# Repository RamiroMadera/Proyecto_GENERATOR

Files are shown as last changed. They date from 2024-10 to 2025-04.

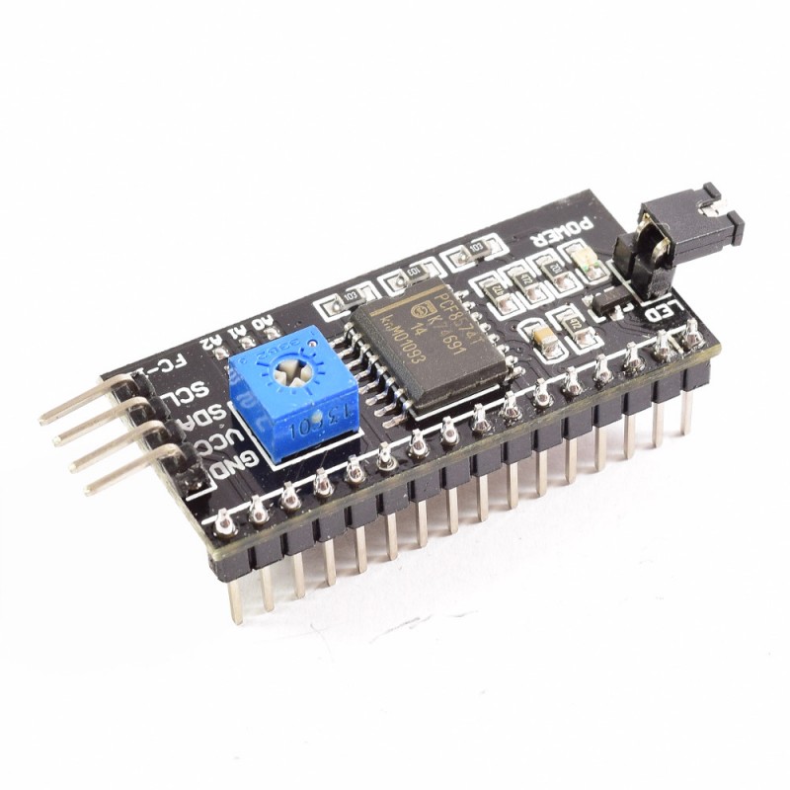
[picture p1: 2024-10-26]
firmware_v3/examples/c/sapi/lcd/lcd_i2c/I2C expander PCF8574/modulo-adaptador-lcd-a-i2c_PCF8574.jpg

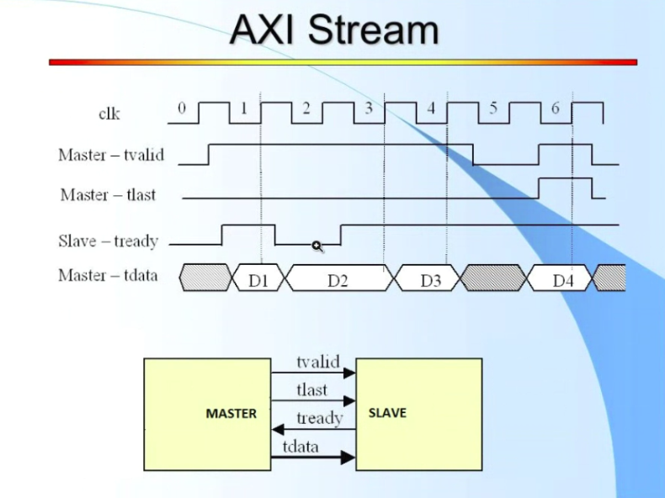
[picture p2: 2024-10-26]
firmware_v3/examples/c/sapi/gpio/axis_interface/AXI Stream.png

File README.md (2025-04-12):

# GENERATOR 🎲  
**Consola electrónica portátil para jugar a la Generala**  
Dispositivo desarrollado con la **EDU-CIAA-NXP** que emula tiradas de dados, combinaciones y puntajes del tradicional juego de Generala. Integra una pantalla táctil, efectos de sonido, sensores de movimiento y una interfaz gráfica atractiva, todo en un sistema autónomo alimentado por batería.

---

## 🎮 Características principales

- **Simulación de tiradas de Generala**
  - Aleatorización de dados entre 1 y 6.
  - Selección de dados para conservar y volver a tirar.
  - Evaluación automática del puntaje y combinaciones.

- **Pantalla gráfica interactiva**
  - Display TFT 2.8" con controlador **ILI9341**.
  - Interfaz táctil basada en **XPT2046** para seleccionar dados y comenzar partidas.

- **Detección de movimiento**
  - Sensor **MPU6050** para identificar la agitación del dispositivo y gatillar la tirada.

- **Sistema de audio**
  - Generación de sonidos con DAC de 10 bits.
  - Amplificación mediante **LM386**.
  - Efectos que acompañan la agitación, la tirada y la obtención de una Generala.

- **Portabilidad total**
  - Alimentado por una batería externa de **5100 mAh**, con una autonomía estimada de más de **16 horas** de juego continuo.

---

## 🧠 Arquitectura del sistema

- **Microcontrolador:** EDU-CIAA-NXP  
- **Interacción por estados:** Inicio → Reposo → Sacudiendo 
- **Firmware en C** desarrollado bajo **CIAA Launcher** 

---

## 📦 Instalación

1. Clona el repositorio:
   ```bash
   git clone https://github.com/RamiroMadera/Proyecto_GENERATOR.git
   ```
2. Abrí el proyecto con CIAA Launcher.
3. Compila y carga el firmware a la placa.
4. Conecta los periféricos según el [esquemático incluido](https://github.com/RamiroMadera/Proyecto_GENERATOR/blob/main/kicad/GENERATOR_Esquematico.pdf).
5. ¡Listo para jugar!

---

## 📚 Documentación técnica

El proyecto cuenta con documentación completa en el informe final del curso "Taller de Proyecto I" de la Facultad de Ingeniería (UNLP), que incluye:

- Requerimientos de hardware y software
- Diseño esquemático y PCB en KiCad
- Arquitectura del firmware y máquina de estados
- Métodos de aleatorización
- Validación del sistema y videos de prueba

[📄 Informe Final (PDF)](https://github.com/RamiroMadera/Proyecto_GENERATOR/blob/main/docs/InformeFinal-Grupo8-TallerDeProyectoI.pdf)

---

## 🧪 Validación y videos

Se ha validado el correcto funcionamiento de todos los requerimientos. Puedes ver los resultados en esta [playlist de YouTube](https://www.youtube.com/playlist?list=PLVBSSKjP-CQ1Y1-SsgbkpVqvSBivJ-5Vr), que muestra:

- Encendido/apagado  
- Tiradas completas  
- Selección de dados  
- Sonido y efectos especiales  
- Reconocimiento de combinaciones y puntajes

---

## 🛠️ Créditos

**Autores:**  
- Tobias Garcia Iacovelli  
- Ramiro Madera  
- Ulises Pereira  

Este proyecto fue desarrollado como parte del curso **Taller de Proyecto I** en la **Facultad de Ingeniería, Universidad Nacional de La Plata**.

---

## 🚀 Próximos pasos

- Añadir sistema de historial de puntajes  
- Incorporar carcasa protectora  
- Expansión a múltiples juegos de dados  
- Conectividad en red para multijugador o leaderboard en la nube

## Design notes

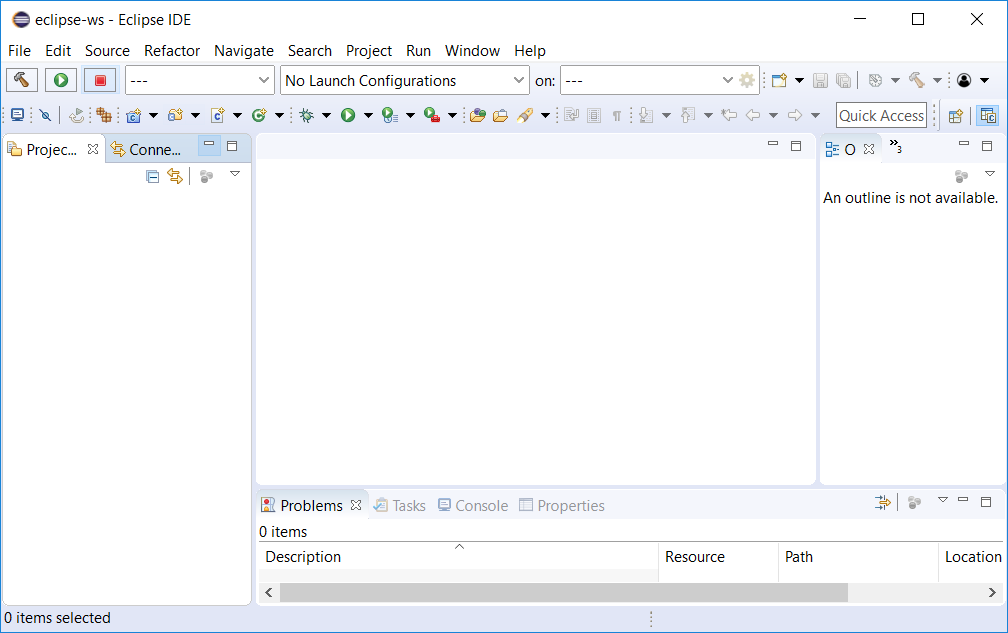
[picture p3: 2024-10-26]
firmware_v3/documentation/firmware/eclipse/Eclipse-Win03.png

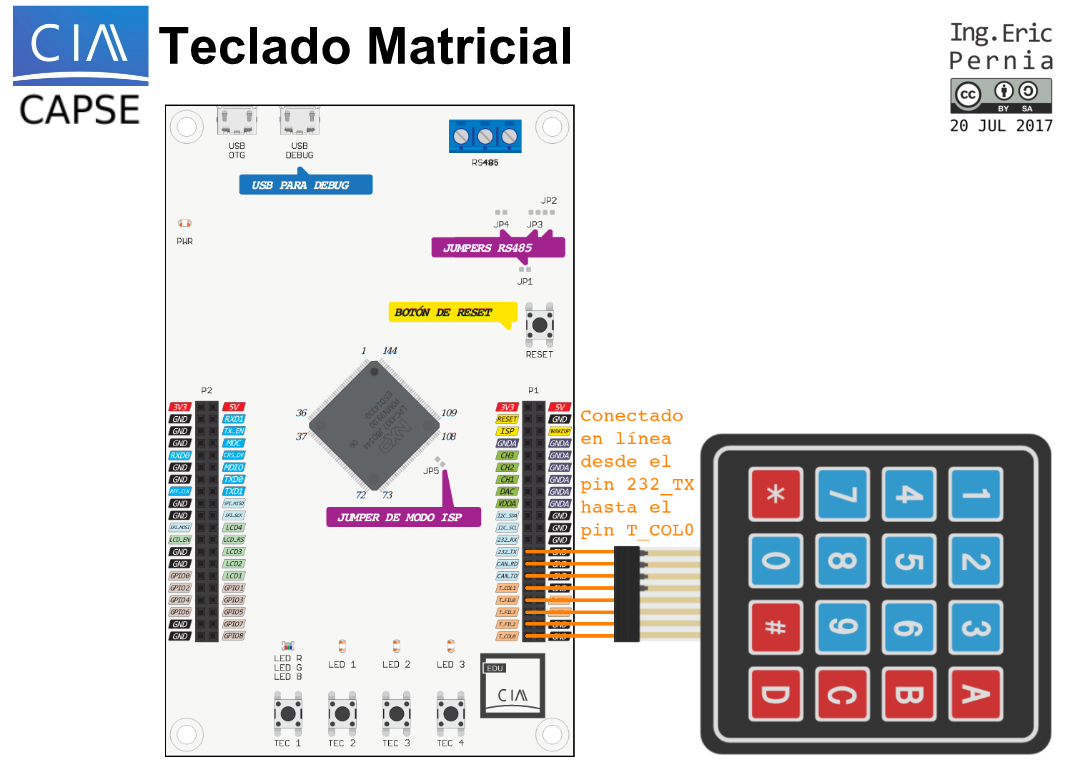
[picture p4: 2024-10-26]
firmware_v3/examples/c/sapi/usb/device/hid_numeric_keypad/Keypad - EDU-CIAA-NXP.png

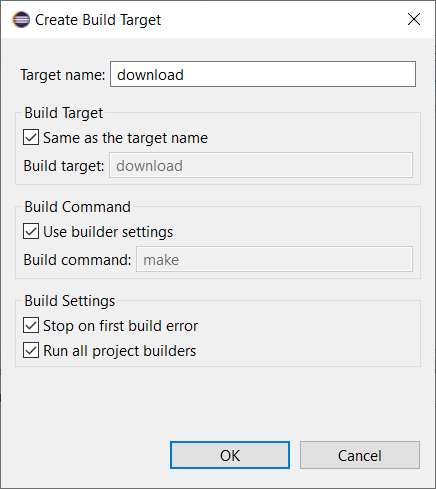
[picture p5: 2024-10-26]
firmware_v3/documentation/firmware/eclipse/targets-04.png

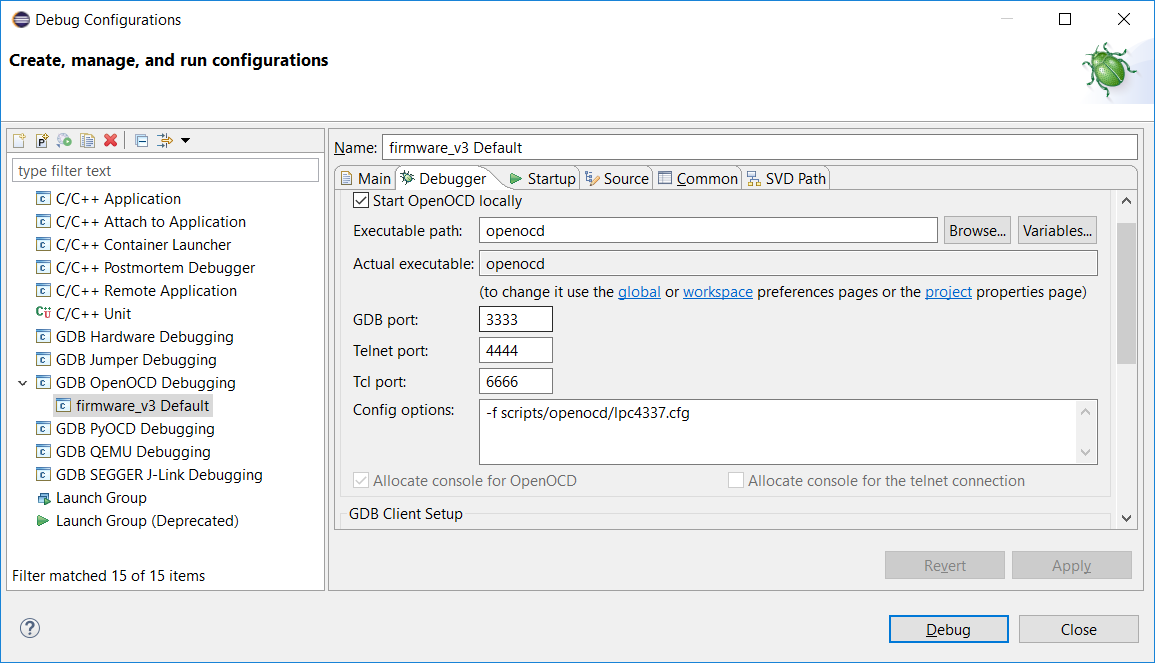
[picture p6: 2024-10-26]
firmware_v3/documentation/firmware/eclipse/Eclipse-Win18.png

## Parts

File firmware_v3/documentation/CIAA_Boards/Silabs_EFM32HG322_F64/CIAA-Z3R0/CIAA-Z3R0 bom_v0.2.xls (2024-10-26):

Reference | Quantity | Value | Footprint | Part number | digikey part number
C12 | 1 | 4.7u | Capacitor 0603 | CC0603KRX5R7BB475 | 311-1785-1-ND
C2 C3 C4 C5 C6 | 5 | 100n | Capacitor 0603 | CC0603KRX7R7BB104 | 311-1088-1-ND
C8 | 1 | 10u | Capacitor 0603 | GRM188R61C106KAALD | 490-10728-1-ND
C1 C10 C11 C7 C9 | 5 | 1u | Capacitor 0603 | CC0603KRX7R7BB105 | 311-1446-1-ND
D1 D3 | 2 | LED GREEN | LED 0805 | LTST-C170GKT | 160-1179-1-ND
D2 | 1 | PMEG2005CT | SOT-23-3 | PMEG2005CT,215 | 1727-5188-1-ND
D4 | 1 | SD0603S040S0R2 | Diode 0603 | SD0603S040S0R2 | 478-7798-1-ND
U1 | 1 | EFM32HG-48LQFP | LQFP-48 7x7mm Pitch 0.5mm | EFM32HG322F64G-B-QFP48 | 336-3835-ND
U2 | 1 | SPX3819M5-L-3-3 | SOT-23-5 | SPX3819M5-L-3-3/TR | 1016-1873-1-ND
U3 | 1 | USBLC6-2 | SOT-23-6 | USBLC6-2SC6 | 497-5235-1-ND
SW1 SW2 | 2 | Switch EVQ-PE105K | Switch SPST-NO 6mm x 3.5mm | EVQ-PE105K | P13594SCT-ND
J3 | 1 | USB Micro-B | USB_Micro-B_Molex_47346-0001 | Molex 473460001 | WM17141CT-ND
J4 | 1 | Header SMD 2x2 Pitch 2.54mm | Pin Header 2x2 Pitch 2.54mm SMD | M20-8760242 | 952-3254-ND
R1 R2 | 2 | 15R | Resistor 0603 | RC0603JR-0715RL | 311-15GRCT-ND
R3 R4 R5 R6 | 4 | 1K | Resistor 0603 | RC0603JR-0710KL | 311-10KGRCT-ND

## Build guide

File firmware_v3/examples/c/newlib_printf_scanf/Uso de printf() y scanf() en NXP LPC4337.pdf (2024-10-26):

# Uso de printf() y scanf() en el microcontrolador NXP LPC4337

# Biblioteca newlib, printf() y scanf() completas o reducidas

La biblioteca estándar de C llamada newlib, que incluye el compilador arm-none-eabi del NXP LPC4337 (el microcontrolador que tiene al EDU-CIAA-NXP o la CIAA-NXP) permite utilizar printf() y scanf() con el microcontrolador.

La biblioteca newlib permite ser compilada en 2 versiones. Una versión completa y una versión reducida nombrada newlib nano.

Si se utiliza newlib nano printf() y scanf() no permiten imprimir o recibir valores en punto flotante (float).

Para desactivar newlib nano y que compila la new lib completa en la carpeta app del proyecto, el archivo config.mk poner:

USE_NANO=n

Por defecto viene en y (que si use nano).

De esta manera podemos poner en un programa:

printf( "Pi vale aproximadamente %f\n", 3.14 );

scanf() y printf() utilizan la UART2 del microcontrolador (UART_USB en la sAPI) como entrada/salida estándar por lo que no se debería reconfigurar la UART2, la está configurada por defecto a 115200 baudios. Esto se hace en el startup del microcontroaldor.

Entonces un programa básico que utilice printf() puede ser simplemente:

#include "sapi.h" // <= Biblioteca sAPI, o alternativamente puede

| // usarse board.h que incluye LPCOpen
int main( void )
{
printf( "Pi vale aproximadamente %f\n", 3.14 ); while( TRUE );
return 0;
}

NOTA:

Si usan printf() en un microcontrolador van a notar que no imprime directamente (envía directo a la UART) si no que lo hace a través de un buffer el cual se envía a la salida estándar, en nuestro caso la UART.

En un programa en la PC si no hay \n este buffer se envía a la salida estándar cuando se llama a la función fflush(), la cual por ejemplo se llama cuando termina el programa.

En embebidos el programa no termina nunca (por el while(1)), entonces hay que forzar el fflush de 2 formas:

1. Llamando a la función fflush():

fflush(stdout);

2. Con \n dentro del texto de printf()

printf( "Hola\n" );

# Uso de memorias del microcontrolador

Se puede probar compilar el mismo programa con la opción USE_NANO en "y" y también en "n" y observar la diferencia de ocupación de memorias.

### Con newlib nano

text | data | bss | dec | hex filename
11460 | 300 | 76 | 11836 | 2e3c app/out/app.elf

En este caso printf() no imprime los valores float %f, pero no da errores, simplemente los ignora.

### Con newlib completa

text | data | bss | dec | hex filename
28992 | 2676 | 152 | 31820 | 7c4c app/out/app.elf

En este caso printf() funciona con todas sus características.

Para comprender esos números, todos están en bytes y representan:

- text - contiene el código compilado y datos de sólo lectura (read-only) de la aplicación (el valor de bytes está en decimal).
- data - shows the read-write data in your application (el valor de bytes está en decimal).
- bss - Muestra los datos inicializados con 0 ('bss' y 'common') en la aplicación (el valor de bytes está en decimal).
- dec - Total = 'text' + 'data' + 'bss' (el valor de bytes está en decimal).
- hex - El valor de bytes en hexadecimal equivalente al de 'dec'.

Esto típicamente se interpreta como:

- Consumo de FLASH de la aplicación equivale a text + data.
- Consumo de RAM de la aplicación equivale a data + bss.

Más información en: http://www.support.code-red-tech.com/CodeRedWiki/FlashRamSize

Como puede observarse, newlib completa ocupa muchos más recursos.

# Uso de printf() y scanf()

## printf()

Las funciones de la familia printf producen una salida de acuerdo a format como se describe abajo. Printf y vprintf escriben su salida a stdout, el flujo de salida estándar. fprintf y vfprintf escriben su salida al stream de salida dado. sprintf, snprintf, vsprintf y vsnprintf escriben a una cadena de caracteres str.

### Prototipo o declaración

int printf( const char *format, ... );

### Ejemplos

printf("Strings:\n");
const char* s = "Hello";
printf("\t.%10s.\n\t.%-10s.\n\t.%*s.\n", s, s, 10, s);

printf("Characters:\t%c %%\n", 65);

printf("Integers\n");
printf("Decimal:\t%i %d %.6i %i %.0i %+i %u\n",1,2,3,0,0,4,-1); printf("Hexadecimal:\t%x %x %X %#x\n", 5, 10, 10, 6); printf("Octal:\t%o %#o %#o\n", 10, 10, 4);

printf("Floating point\n");
printf("Rounding:\t%f %.0f %.32f\n", 1.5, 1.5, 1.3); printf("Padding:\t%05.2f %.2f %5.2f\n", 1.5, 1.5, 1.5); printf("Scientific:\t%E %e\n", 1.5, 1.5); printf("Hexadecimal:\t%a %A\n", 1.5, 1.5);

### Los caracteres % (especificaciones de conversión)

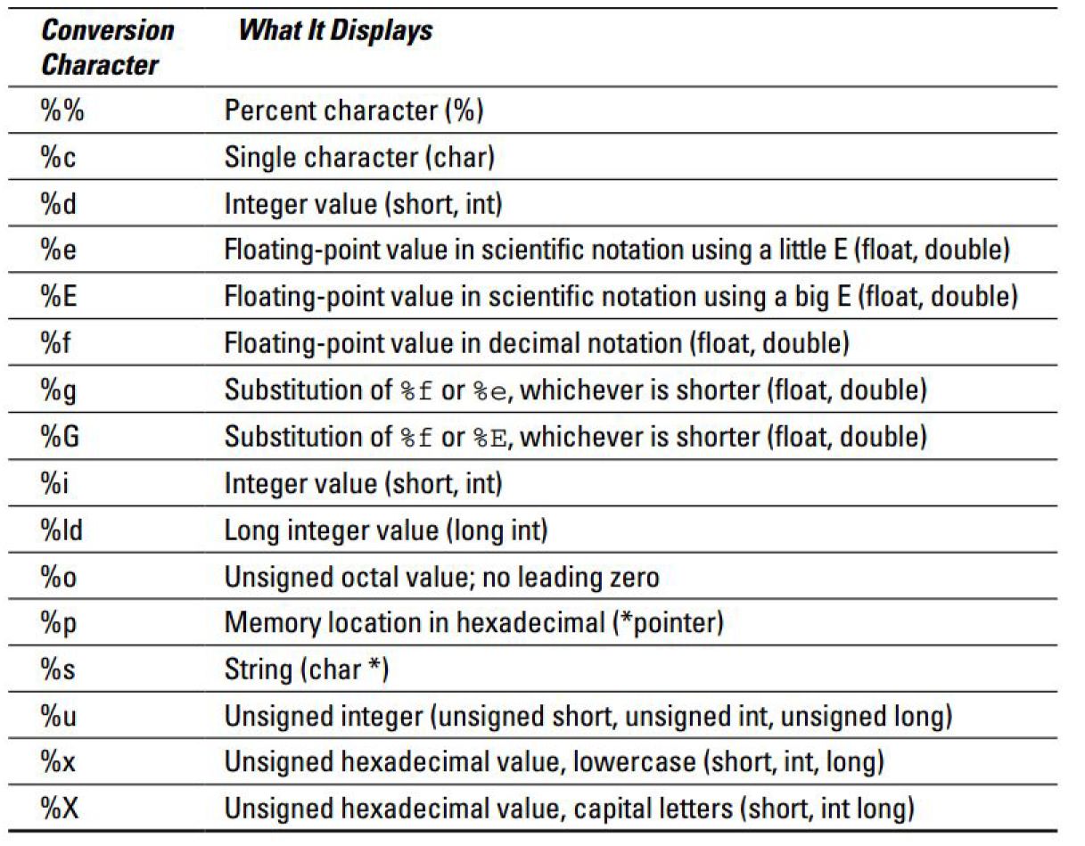
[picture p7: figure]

### Más información

- http://es.tldp.org/Paginas-manual/man-pages-es-1.28/man3/printf.3.html
- https://es.cppreference.com/w/c/io/fprintf

## scanf()

La familia scanf de funciones busca en la entrada según un formato como se describe más adelante. Este formato puede contener especificadores de conversión; los resultados de tales conversiones, si las hay, se guardan donde apunten los argumentos punteros. La
función scanf | lee la entrada del flujo de entrada estándar stdin, fscanf | lee su entrada del
puntero a FILE flujo, y sscanf | lee su entrada de la cadena de caracteres a la que apunte str.

### Prototipo o declaración

int scanf( const char *format, ... );

### Ejemplo

char text[50];
printf( "Ingrese un texto y presione enter:\r\n" ); scanf( "%s", text );
printf( "El texto ingresado es: %s\r\n", text );

### Los carcateres % (especificaciones de conversión)

%c para indicar entrada de un caracter
%d para indicar entrada de un entero
%f para indicar entrada de un flotante
%s para indicar entrada de un string

### Sugerencias para el uso de scanf()

- Antes de usar scanf, imprimir con printf() indicando al usuario qué tipo de dato o información debe ingresar.
- Ingresar de a un dato por vez. Será mejor que cada llamado a scanf() sea para ingresar un dato, evitar el ingreso múltiple.
- Para ingresar texto, indicar el máximo de caracteres que scanf() debe aceptar, así no almacena en zonas inapropiadas.

### Más información

- http://es.tldp.org/Paginas-manual/man-pages-es-1.28/man3/scanf.3.html
- https://es.cppreference.com/w/c/io/fscanf

# Ejemplo con scanf() y printf()

#include "sapi.h" // <= Biblioteca sAPI, o alternativamente puede // usarse board.h que incluye LPCOpen

// La UART_USB se inicializa en el startup del microcontrolador a // 115200 baudios para salida y entrada estandar.

// Recordar en config.mk poner USE_NANO=n (usar newlib completa // en lugar de newlib nano) para tener soporte de flotantes en // printf(), sin embargo, esto causa que el programa ocupe MUCHA // mas RAM y FLASH.

int main( void )
{
printf( "Pi vale aproximadamente %f\r\n", 3.14 );

char text[50];
int num;

printf( "Ingrese un texto y presione enter:\r\n" ); scanf( "%s", text );
printf( "El texto ingresado es: %s\r\n", text );

printf( "Ingrese un numero y presione enter:\r\n" ); scanf( "%d", &num );
printf( "El numero ingresado es: %d\r\n", num );

while( TRUE );

return 0;
}

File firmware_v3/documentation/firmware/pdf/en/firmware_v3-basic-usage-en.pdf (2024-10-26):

# firmware_v3 usage

Make sure you have an arm-none-eabi-* toolchain configured in your PATH . If you don't have it, download GCC ARM Embedded. (https://developer.arm.com/open-source/gnu-toolchain/gnu-rm)
Make sure you have an openocd configured in your PATH .

# Select a target board to compile

Create a board.mk text file inside this folder.
Define BOARD variable in board.mk according to the board you want to compile. board.mk example default values:

Note: If you have zenity installed (included in CIAA Software), (https://github.com/epernia/software/) you can use:

make select_board to select graphically a target board.

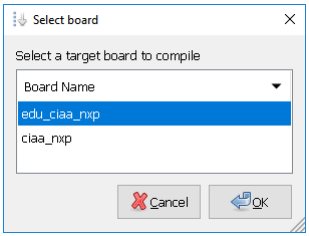
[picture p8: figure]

This will create automaticaly a board.mk text file inside this folder with the selected board.

# Select a program to compile

Create a program.mk text file inside this folder.
Define PROGRAM_NAME and PROGRAM_PATH variables in program.mk according to the program you want to compile (PROGRAM_PATH is relative to this folder, leave void if the

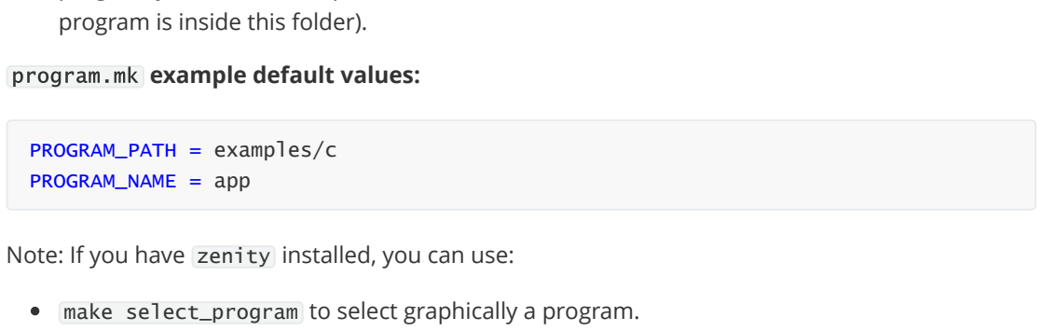
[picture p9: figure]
program is inside this folder).; program.mk example default values:; PROGRAM_PATH = examples/c; PROGRAM_NAME = app

Note: If you have zenity installed, you can use:

make select_program to select graphically a program.

BOARD = edu_ciaa_nxp

This will create automaticaly a program.mk text file inside this folder with the selected program.

# Compile and download

Compile with make .
Download to target via OpenOCD with make download . Clean compilation with make clean .

# Create a new program

Each program consist in a folder (with a non-spaces name) that includes inside 2 folders, one named src (here go, .c, .cpp or .s source code files), and another one named inc (here go, .h or

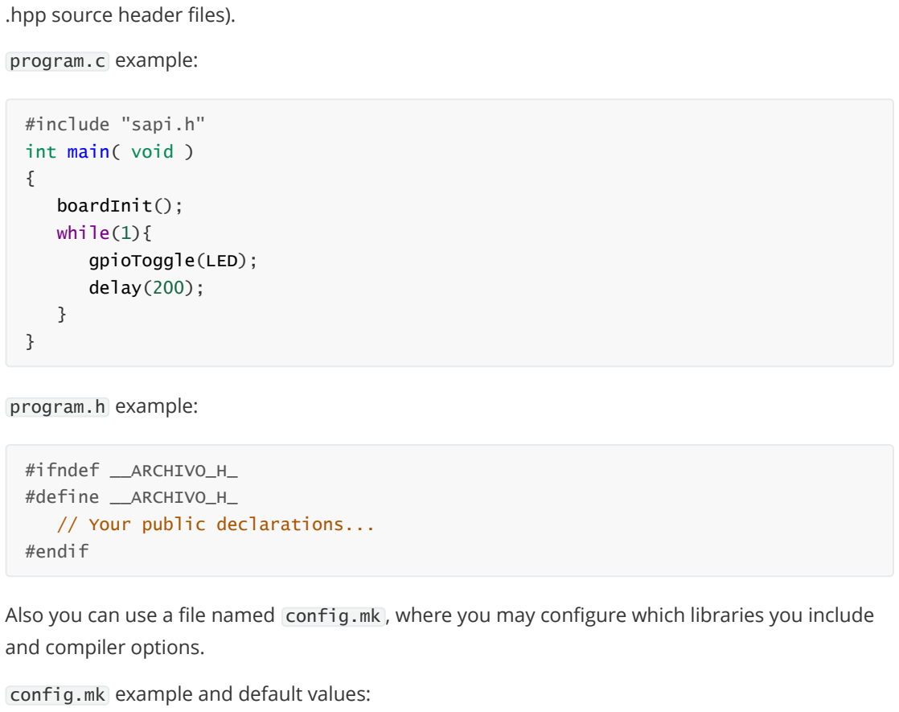
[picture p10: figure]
.hpp source header files).; program.c example:; program.h example:; and compiler options.; config.mk example and default values:; #include "sapi.h"; int main( void ); boardInit();; while(1){; gpioToggle(LED);; delay(200);; #ifndef __ARCHIVO_H_; #define __ARCHIVO_H_; // Your public declarations... #endif

Also you can use a file named config.mk , where you may configure which libraries you include

Program complete structure is:

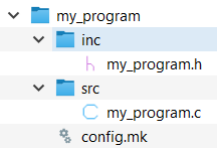
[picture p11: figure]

Note: If you have zenity installed, you can use:

make new_program to create graphically a program using program templates.

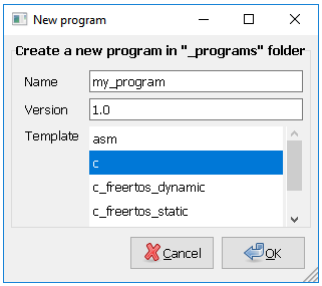
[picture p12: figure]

Note: First time will ask you for your user preferences:

# Compile options

VERBOSE=n
OPT=g
USE_NANO=y
SEMIHOST=n
USE_FPU=y
# Libraries

USE_LPCOPEN=y
USE_SAPI=y

# Create a new global library

The libs folder include libraries that can be used fom any program (global libraries).

The Makefile allow you to include 2 types of libraries:

Simple library. Consist in a folder (with a non-spaces name) that includes inside 2 folders, one named src (here go .c, .cpp or .s source code files), and another one named inc (here go .h or .hpp header files). This kind of library compiles automaticaly by the Makefile. Advanced library. Consist in a library with a complex folder and files structure, i.e. LibUSB. This case require make your own makefile. You can inspire from sAPI makefile to do that.

# More information

Back to README.

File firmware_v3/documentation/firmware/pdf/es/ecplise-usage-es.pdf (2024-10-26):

# Índice

Utilización de firmware_v3 con Eclipse
1. Abrir proyecto firmware_v3 en Eclipse
1.1. Abrir proyecto firmware_v3 en Eclipse por primera vez
1.1.1. Iniciar Eclipse
1.1.2. Workspace
1.1.3. Ventana inicial
1.1.4. Abrir Proyecto de Firmware para programar en asembler, C o C++
1.2. Abrir proyecto firmware_v3 en Eclipse en sucesivas ocasiones
2. Compilar proyecto firmware_v3 en Eclipse
2.1. Configurar opciones de compilación
2.2. Compilar proyecto
3. Configurar y ejecutar targets de makefile en Eclipse
3.1. Targets por defecto en Eclipse
3.2. Configurar targets de makefile en Eclipse
4. Depuración de un programa sobre la plataforma de hardware con Eclipse y firmware_v3
4.1. Configuración de la descarga y depuración del programa sobre el hardware
4.2. Probar el funcionamiento de la depuración sobre el hardware
4.3. Botones de control de ejecución y breakpoints
4.4. Depurar otro programa dentro del mismo proyecto

# Utilización de firmware_v3 con Eclipse

# 1. Abrir proyecto firmware_v3 en Eclipse

## 1.1. Abrir proyecto firmware_v3 en Eclipse por primera vez

### 1.1.1. Iniciar Eclipse

Recordar iniciar Eclipse desde el Launcher. Esto traerá las variables de entorno necesarias para ubicar las herramientas externas para compilación y depuración.

### 1.1.2. Workspace

Al abrir el Eclipse solicita seleccionar la carpeta a utilizar como espacio de trabajo (Workspace), elegir dentro de la ruta donde descomprimieron el Launcher la carpeta:

<rutaDondeDescomprimiElLauncher>/workspaces/eclipse-ws

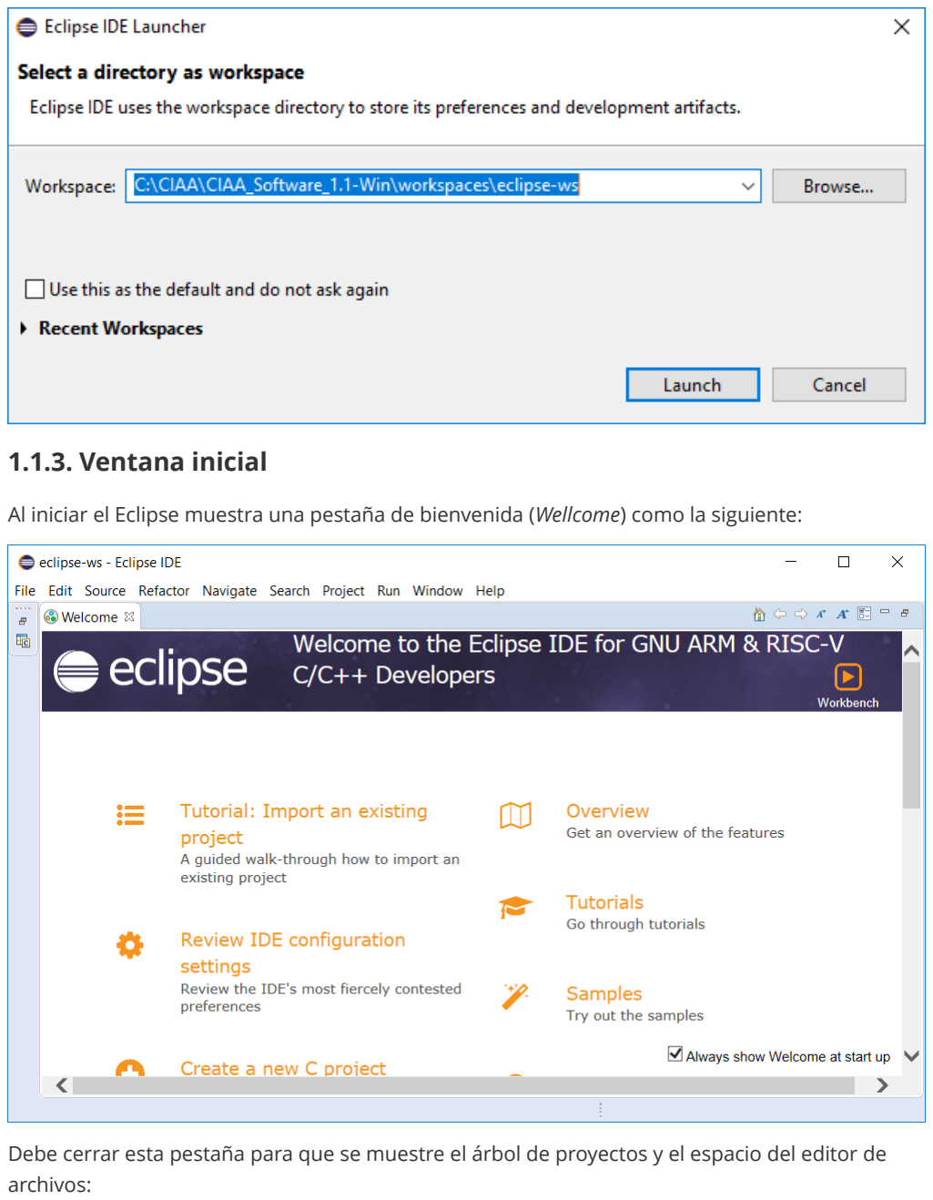
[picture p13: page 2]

### 1.1.3. Ventana inicial

Al iniciar el Eclipse muestra una pestaña de bienvenida (Wellcome) como la siguiente:

Debe cerrar esta pestaña para que se muestre el árbol de proyectos y el espacio del editor de archivos:

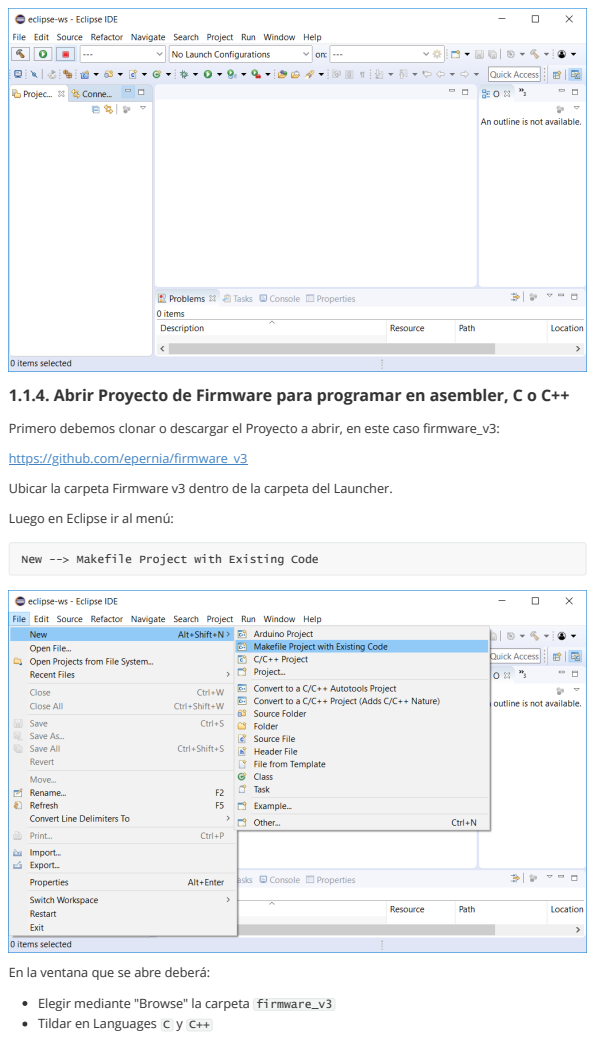
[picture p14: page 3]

1.1.4. Abrir Proyecto de Firmware para programar en asembler, C o C++

Primero debemos clonar o descargar el Proyecto a abrir, en este caso firmware_v3:
https://github.com/epernia/firmware_v3
Ubicar la carpeta Firmware v3 dentro de la carpeta del Launcher.
Luego en Eclipse ir al menú:

New --> Makefile Project with Existing Code

En la ventana que se abre deberá:
Elegir mediante "Browse" la carpeta firmware_v3
Tildar en Languages C y C++

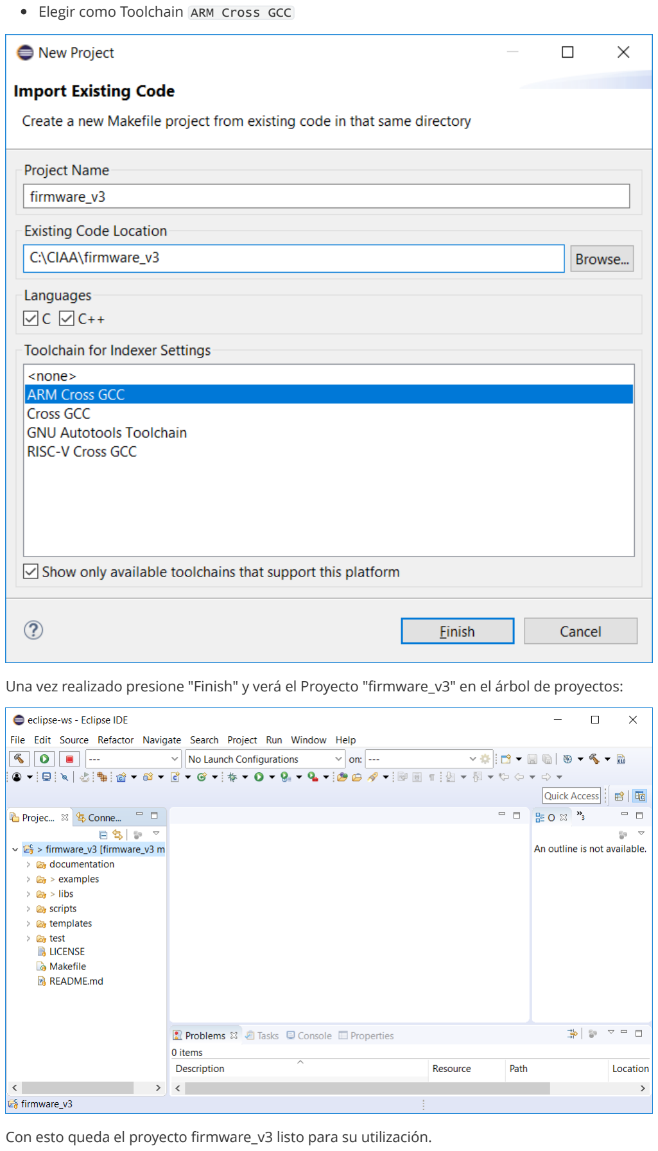
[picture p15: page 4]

Elegir como Toolchain ARM Cross GCC

Una vez realizado presione "Finish" y verá el Proyecto "firmware_v3" en el árbol de proyectos:

Con esto queda el proyecto firmware_v3 listo para su utilización.

Nota: Eclipse puede tener múltiples proyectos en simultáneo dentro de un mismo Workspace. En particular, el proyecto firmware_v3 es un único proyecto que se compone de múltiples programas (los ejemplos que trae más los programas que realizaremos nosotros). Es decir con un único proyecto de Eclipse abierto tendremos la posibilidad de seleccionar que programa del mismo se desea compilar y descargar a la plataforma de hardware.

## 1.2. Abrir proyecto firmware_v3 en Eclipse en sucesivas ocasiones

Eclipse guarda todas las configuraciones realizadas sobre la carpeta elegida como Workspace con y de esta manera al abrir nuevamente Eclipse y seleccionar el Workspace que hemos creado se cargará el proyecto firmware_v3 automáticamente.

# 2. Compilar proyecto firmware_v3 en Eclipse

## 2.1. Configurar opciones de compilación

Se debe hacer click derecho sobre el proyecto "firmware_v3" y luego en la opción "Properties":

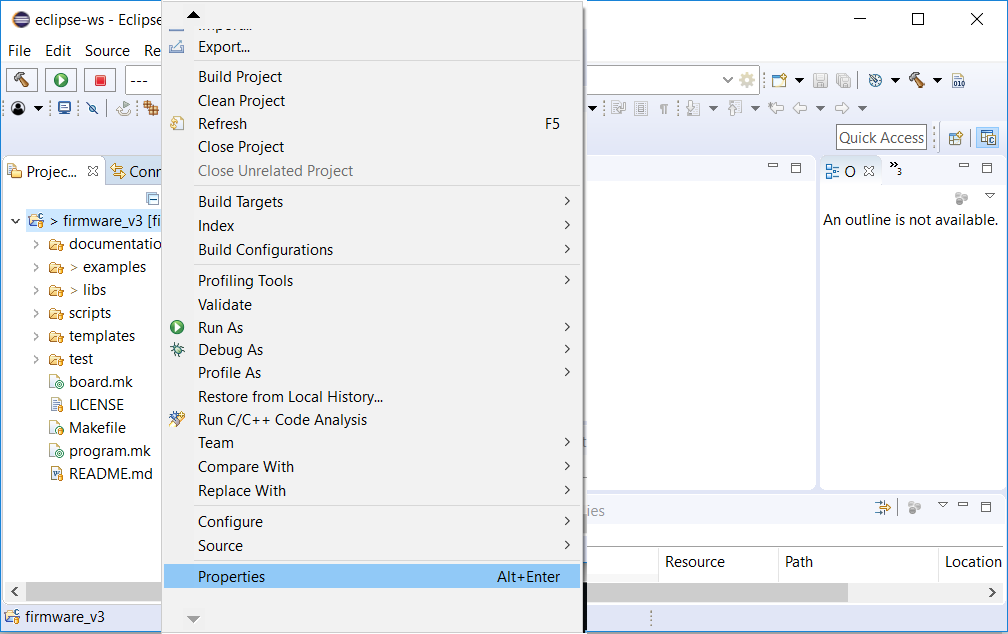
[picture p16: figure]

En la ventana que se abre debe hacer click sobre "C/C++ Build" y en la parte derecha debe: Destildar la opción "Use default build command".
En "Build command" escribir make en el campo de texto.

Presionar "Apply and Close" para aplicar la configuración.

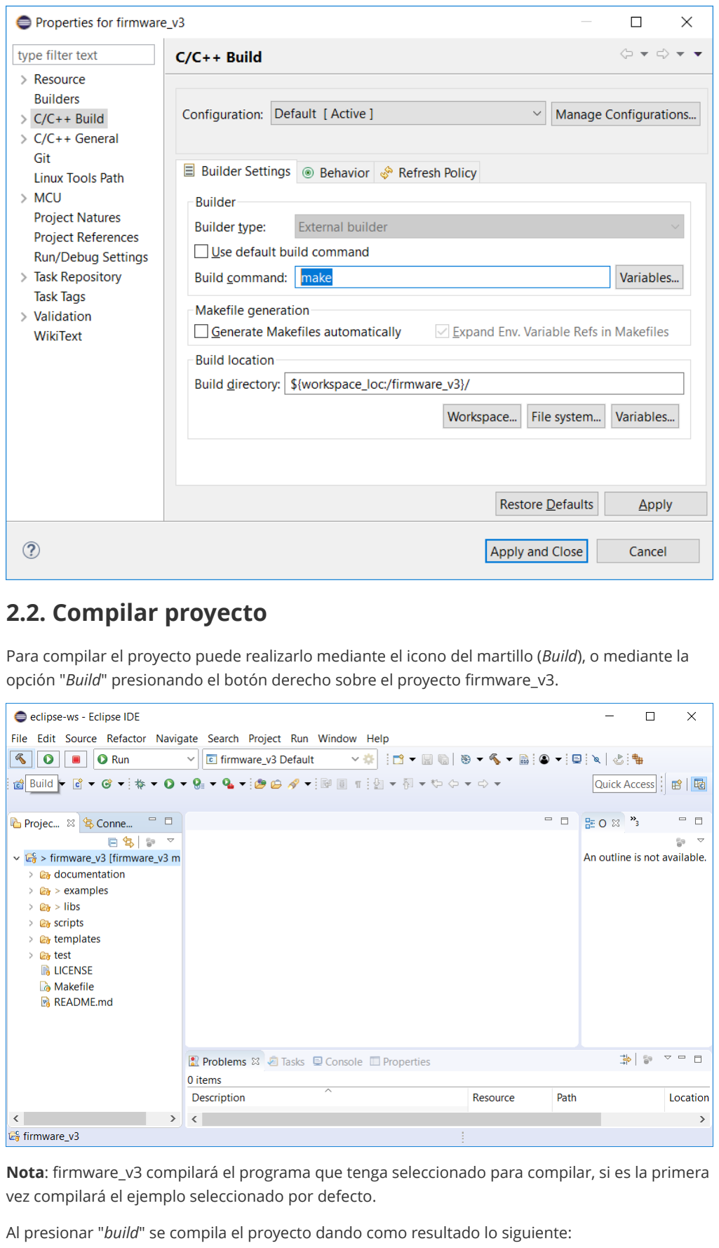
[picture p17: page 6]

## 2.2. Compilar proyecto

Para compilar el proyecto puede realizarlo mediante el icono del martillo (Build), o mediante la opción "Build" presionando el botón derecho sobre el proyecto firmware_v3.

Nota: firmware_v3 compilará el programa que tenga seleccionado para compilar, si es la primera vez compilará el ejemplo seleccionado por defecto.
Al presionar "build" se compila el proyecto dando como resultado lo siguiente:

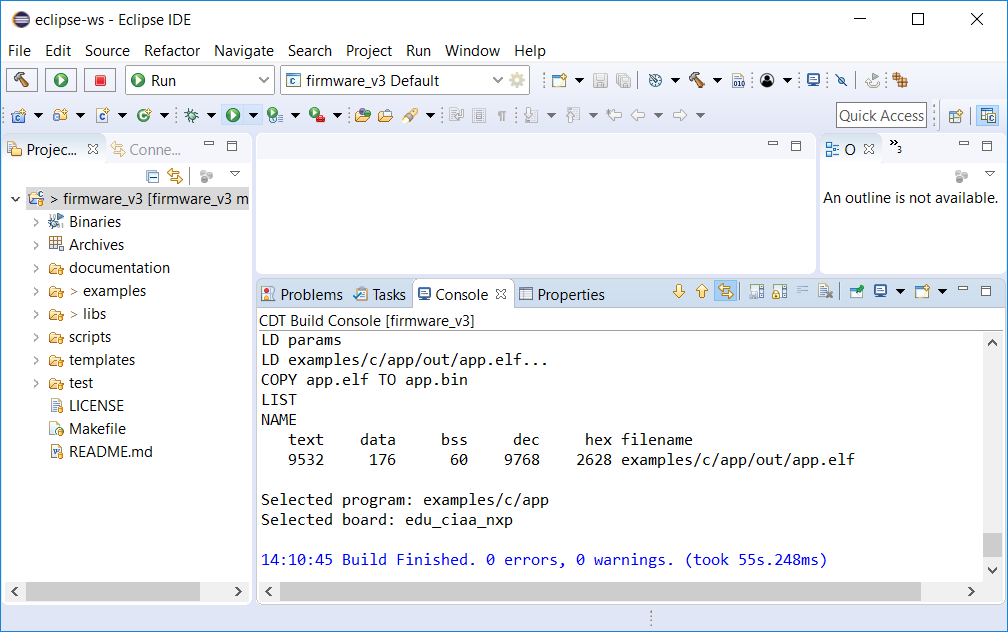
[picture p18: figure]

Nota: observe que se ve:
Los bytes ocupados en cada área de memoria (ver apunte de printf() y scanf() para comprenderlo).
El programa que fue compilado dentro del proyecto, en este caso llamado "app" en la carpeta "examples/c" dentro de "firmware_v3".
La plataforma de hardware para la cual se compiló el programa, en este caso "EDU-CIAA-NXP".

# 3. Configurar y ejecutar targets de de makefile en Eclipse

## 3.1. Targets por defecto en Eclipse

Eclipse muestra algunos de sus targets de diferentes maneras:
El target all como el "botón del martillo" (Build project) accesible desde el menú superior.

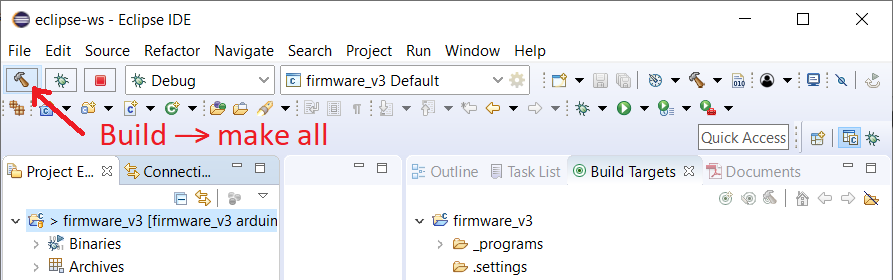
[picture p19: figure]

El botón build ejecuta el comando:

make all
Si se presiona botón derecho del mouse sobre el proyecto firmware_v3 se muestran como opciones del menú contextual:
Build Project. Ejecuta el comando make all

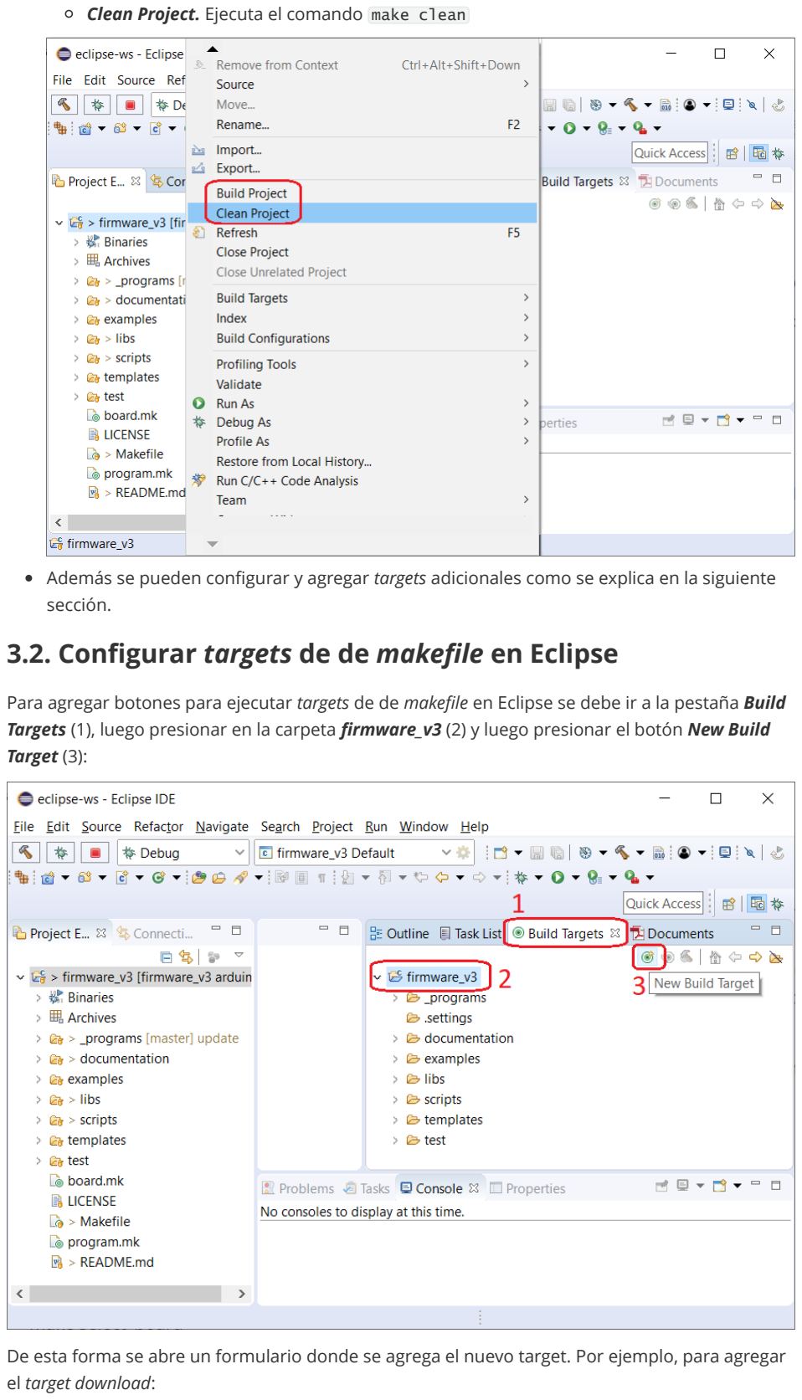
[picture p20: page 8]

Clean Project. Ejecuta el comando make clean

Además se pueden configurar y agregar targets adicionales como se explica en la siguiente sección.

## 3.2. Configurar targets de de makefile en Eclipse

Para agregar botones para ejecutar targets de de makefile en Eclipse se debe ir a la pestaña Build Targets (1), luego presionar en la carpeta firmware_v3 (2) y luego presionar el botón New Build Target (3):

De esta forma se abre un formulario donde se agrega el nuevo target. Por ejemplo, para agregar el target download:

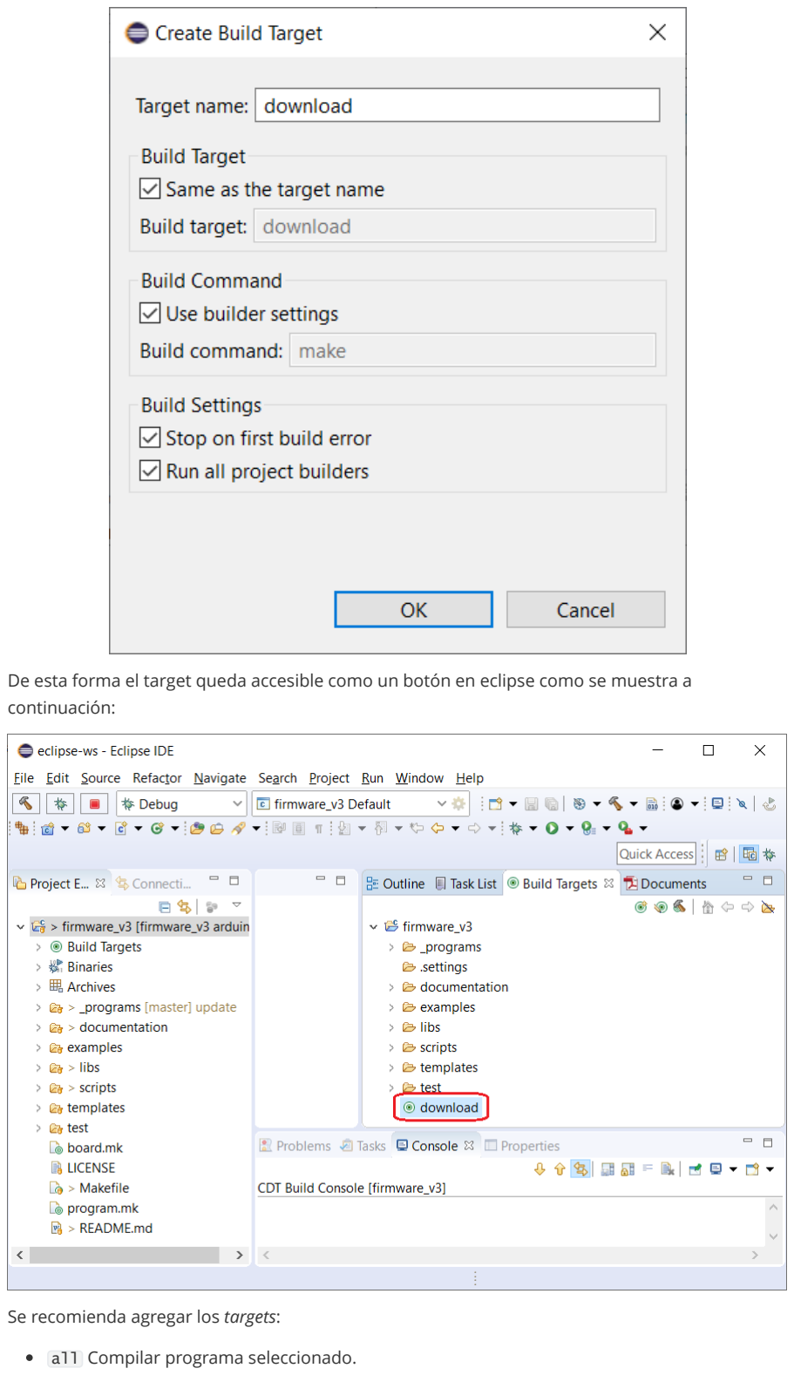
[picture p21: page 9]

De esta forma el target queda accesible como un botón en eclipse como se muestra a continuación:

Se recomienda agregar los targets:

all Compilar programa seleccionado.

clean Eliminar archivos de compilaciones previas (remueve la carpeta out dentro del programa seleccionado). Es necesario ejecutarlo sobre le programa seleccionado al cambiar opciones de compilación del programa (archivo config.mk) o al cambiar la plataforma de hardware (board) para la cual se compilará el programa.
clean_all Eliminar archivos de compilaciones previas de todos los programas dentro de la carpeta firmware_v3.
download Descarga el programa seleccionado a la board seleccionada.
erase Borra la flash de la board seleccionada. Es necesario resetear la plataforma luego de aplicarlo.
new_program Permite gráficamente crear un nuevo programa dentro de la carpeta seleccionada por el usuario (la primera vez se pide el nombre de la carpeta donde se guardaran los programas y se crea dentro de la carpeta firmware_v3).
select_board Permite elegir gráficamente la plataforma de hardware (board) para la cual se compilará el programa.
select_program Permite elegir gráficamente el programa a utilizar (compilar, descargar, limpiar, etc.).
Se ejecutan realizando doble doble click sobre el icono de los mismos.

# 4. Depuración de un programa sobre la plataforma de hardware con Eclipse y firmware_v3

## 4.1. Configuración de la descarga y depuración del programa sobre el hardware

Ubique el ícono del bicho verde (debug) , presione sobre la flecha hacia abajo a la derecha de este icono y en la ventana que se despliega la opción "Debug Configurations..."

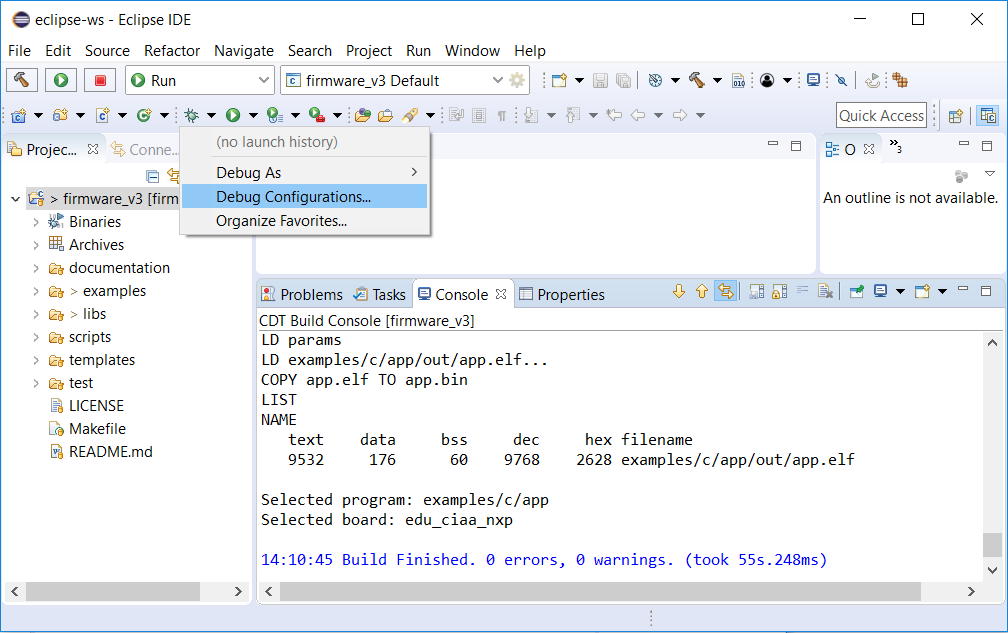
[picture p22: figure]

Esto abre la ventana de configuraciones:

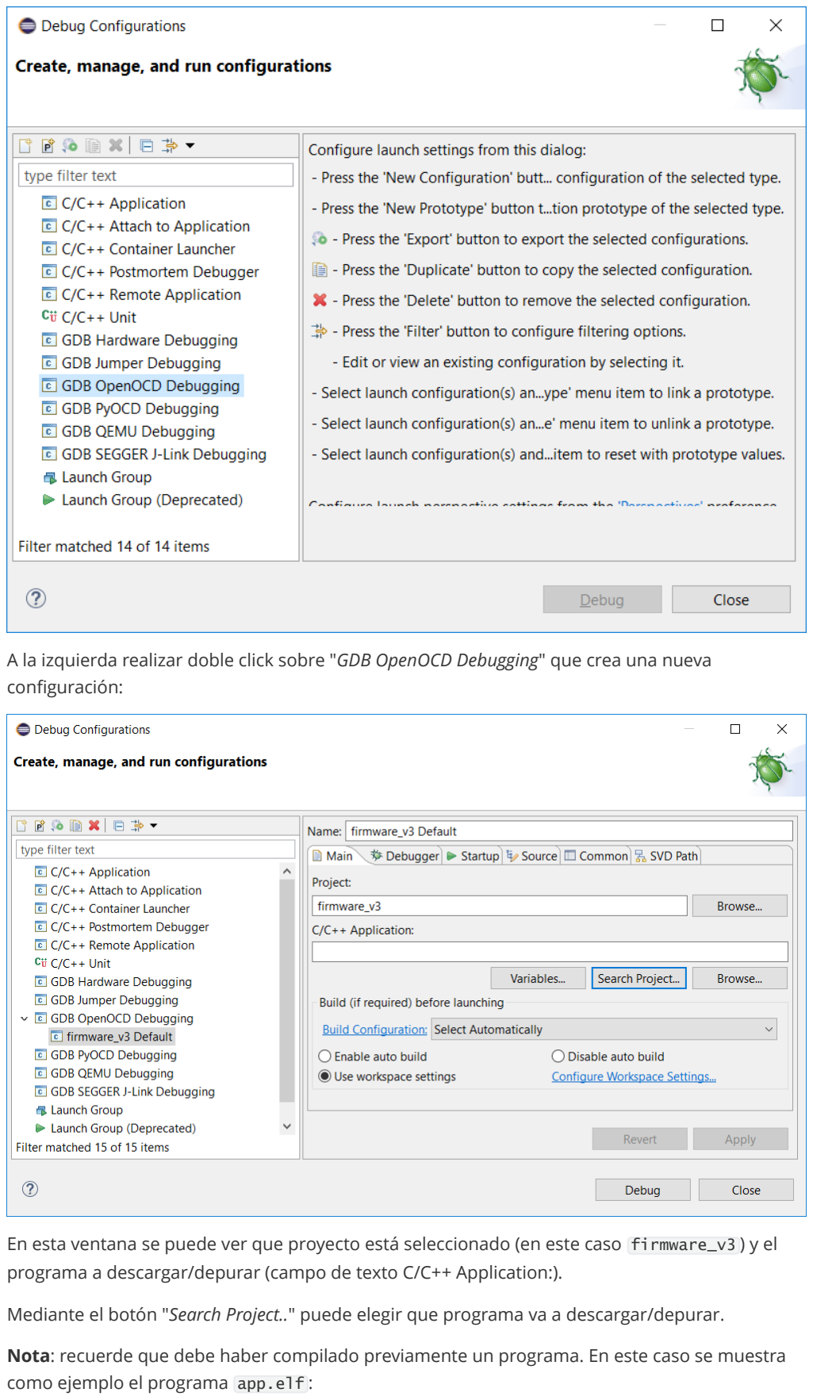
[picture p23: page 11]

A la izquierda realizar doble click sobre "GDB OpenOCD Debugging" que crea una nueva configuración:

En esta ventana se puede ver que proyecto está seleccionado (en este caso firmware_v3 ) y el programa a descargar/depurar (campo de texto C/C++ Application:).

Mediante el botón "Search Project.." puede elegir que programa va a descargar/depurar.
Nota: recuerde que debe haber compilado previamente un programa. En este caso se muestra como ejemplo el programa app.elf :

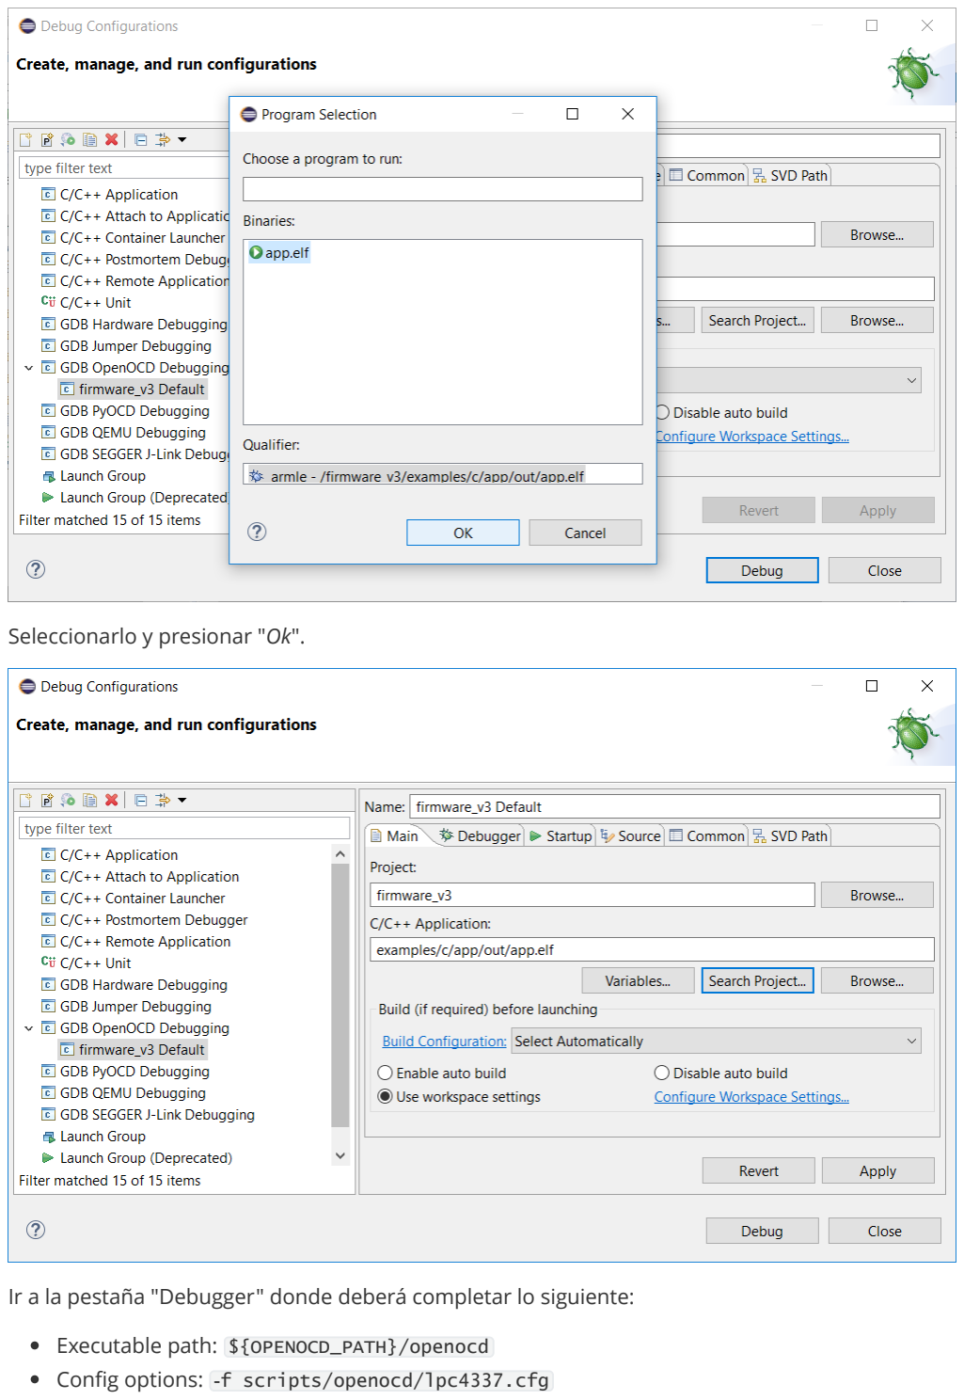
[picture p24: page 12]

Seleccionarlo y presionar "Ok".

Ir a la pestaña "Debugger" donde deberá completar lo siguiente:

Executable path: ${OPENOCD_PATH}/openocd

Config options: -f scripts/openocd/lpc4337.cfg

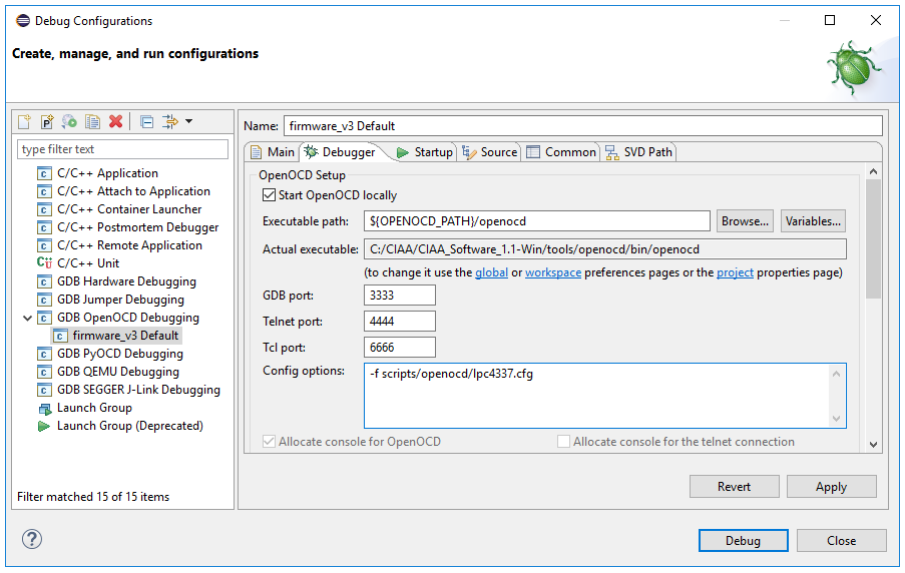
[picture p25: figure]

Deslice la pantalla más abajo y configure en la sección "GDB Client Setup":

Executable name: arm-none-eabi-gdb

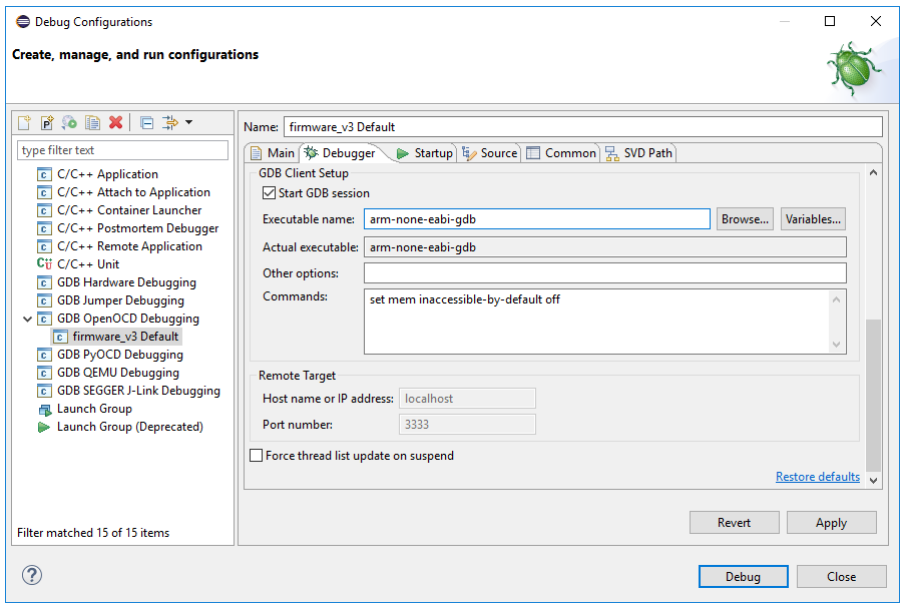
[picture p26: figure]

Con esto ya se encuentra configurado el Eclipse para depurar.

## 4.2. Probar el funcionamiento de la depuración sobre el hardware

Para probarlo presione sobre el botón "Debug". Aparecerá un mensaje como el siguiente la primera vez que avisa que el Eclipse pasará de la perspectiva de programación, a la de depuración (esto hace que se reacomoden vairos menues para facilitar la depuración). Presione "Remember my decision" y "Switch" para que no la muestre cada vez:

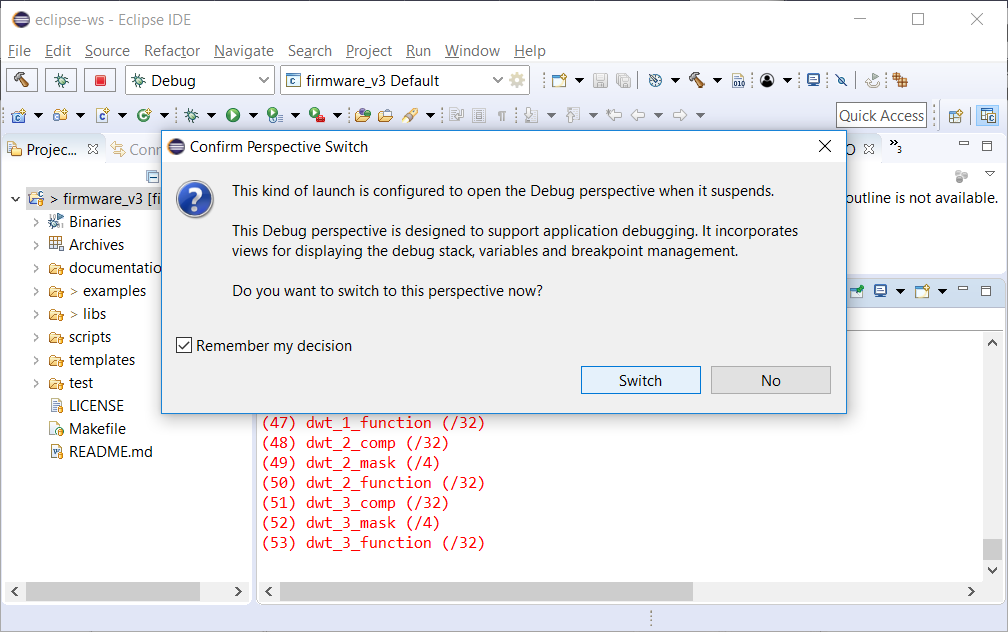
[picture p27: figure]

Cuando el programa se descargó a la plataforma y empezó a ejecutarlo dentendrá su ejecución al inicio de la función main().

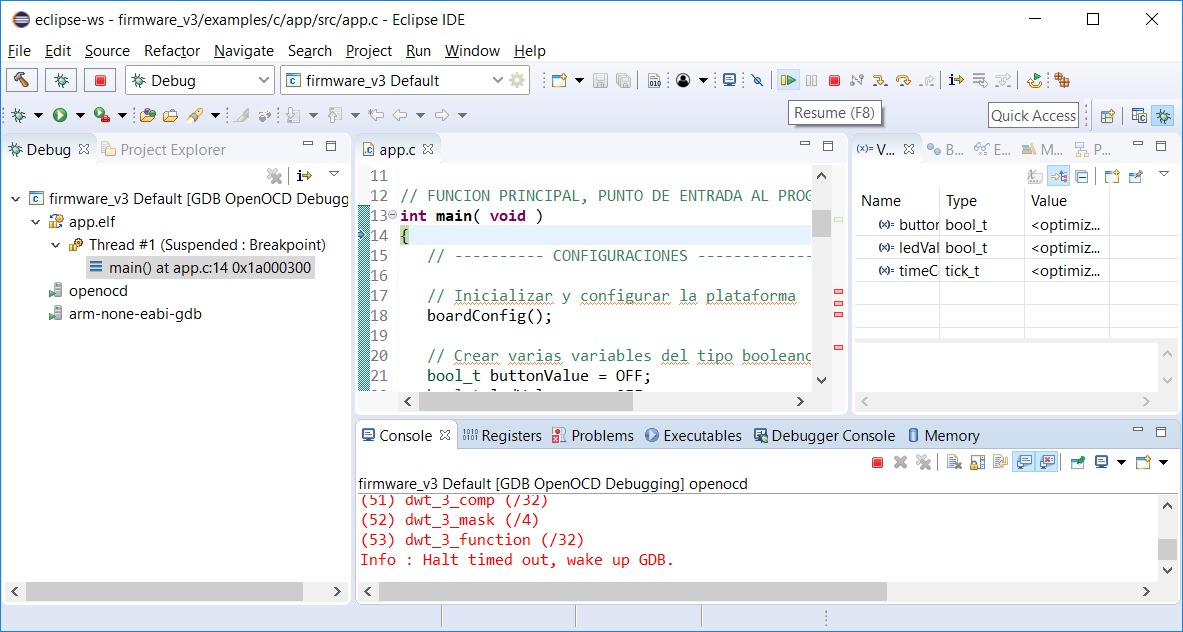
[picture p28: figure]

## 4.3. Botones de control de ejecución y breakpoints

Mediante los botones de control de ejecución y breakpoints podremos controlar el programa que se ejecuta en la placa desde nuestra PC:

De izquierda a derecha:
Skip All Breakpoints (Ctrl+Alt+B). Habilitar/Deshabilitar breakpoints.
Resume (F8). Correr el código hasta el próximo breakpoint o de forma continua.
Suspend. Detener la ejecución del programa.
Terminate (Ctrl+F2). Terminar sesión de debug con botón stop.
Connect/Disconnect. Botón conectar o desconectar (siempre deshabilitado, no se utiliza en firmware_v3).

Step Into (F5). Ejecuta un paso dentro de la próxima función llamada.
Step Over (F6). Ejecuta un paso en una instrucción del código.
Step Return (F7). Ejecuta un paso fuera de la función actual.
Además se puede agregar o eliminar un breakpoint mediante doble click en el área gris a la izquierda de las líneas de código).

En este ejemplo se puso un beakpoint en la función boardConfig() :

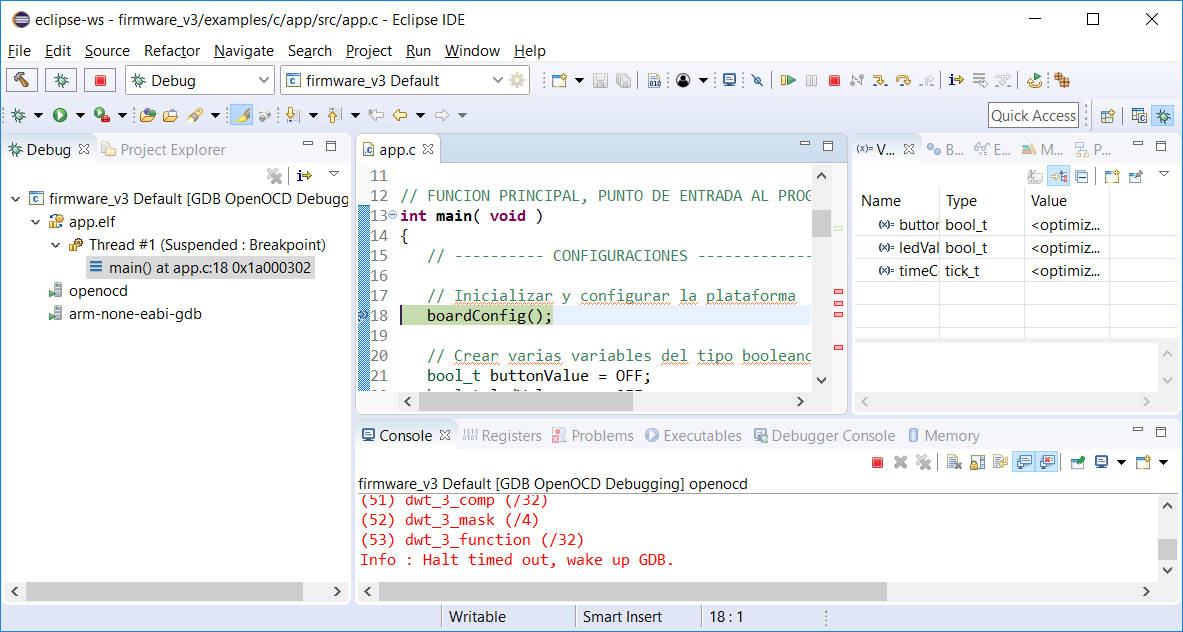
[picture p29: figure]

## 4.4. Depurar otro programa dentro del mismo proyecto

Simplemente deberá compilar el otro programa y luego abrir la ventana "Debug Configurations" y mediante el botón "Search Project.." puede elegir que programa va a descargar/depurar:

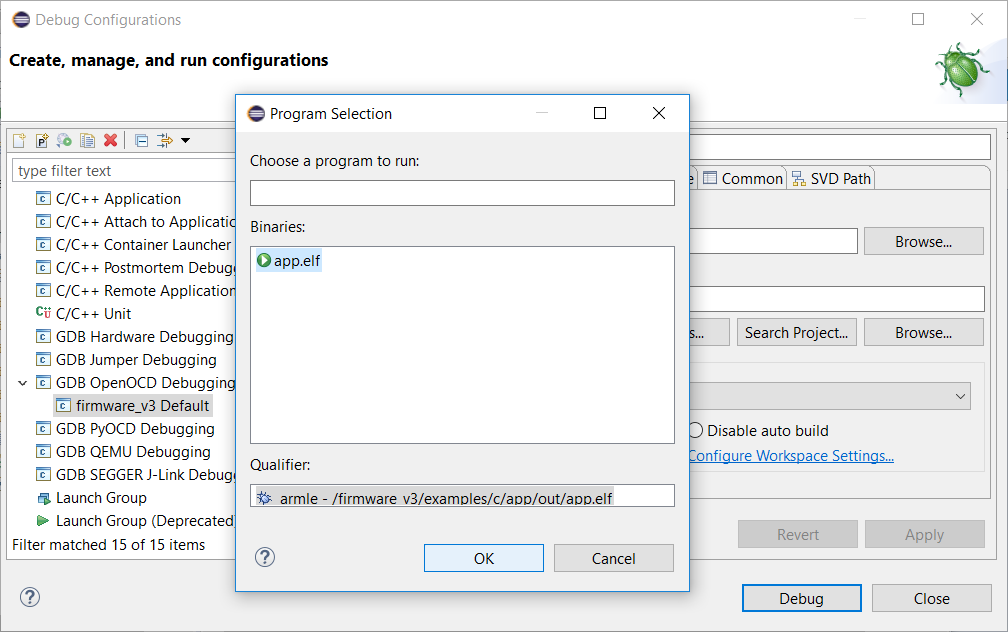
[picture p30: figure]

NOTA: Recuerde que previamente debe haber compilado el programa a depurar para que aparezca en la búsqueda.
Luego simplemente presionar sobre debug, el resto de las configuraciones que realizamos se hace una única vez.

# Más información

Volver al README.

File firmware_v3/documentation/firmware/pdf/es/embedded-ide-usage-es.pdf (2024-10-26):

# Índice

Utilización de firmware_v3 con Embedded IDE
1. Abrir el proyecto firmware_v3 en Embedded IDE
1.1. Iniciar Embedded IDE
1.2. Proyectos soportados por Embedded IDE
1.3. Abrir el proyecto firmware_v3
2. Ejecutar targets de makefile en Embedded IDE

# Utilización de firmware_v3 con Embedded IDE

# 1. Abrir el proyecto firmware_v3 en Embedded IDE

## 1.1. Iniciar Embedded IDE

Recordar iniciar Embedded IDE desde el Launcher. Esto traerá las variables de entorno necesarias para ubicar las herramientas externas para compilación y depuración.

## 1.2. Proyectos soportados por Embedded IDE

Embedded soporta proyectos en base a Makefile. Al abrir un proyecto con Makefile Embedded IDE busca automáticamente todos los objetivos (targets) del mismo y los presenta como botones accesibles en el panel inferior izquierdo del IDE.

## 1.3. Abrir el proyecto firmware_v3

Para abrir el proyecto "firmware_v3" en Embedded IDE primero debe abrir el propio Embedded IDE y luego presionar sobre "Abrir proyecto" (o el atajo de teclado Ctrl+o) como se muestra a continuación:

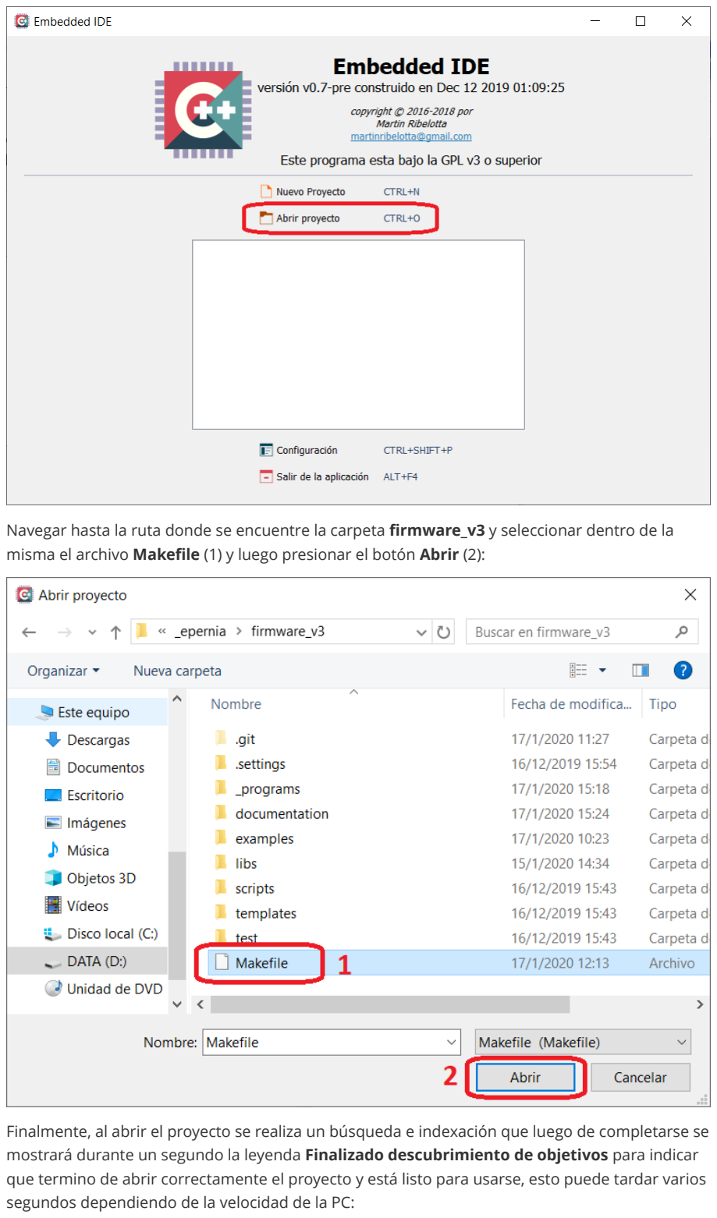
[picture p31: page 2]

Navegar hasta la ruta donde se encuentre la carpeta firmware_v3 y seleccionar dentro de la misma el archivo Makefile (1) y luego presionar el botón Abrir (2):

Finalmente, al abrir el proyecto se realiza un búsqueda e indexación que luego de completarse se mostrará durante un segundo la leyenda Finalizado descubrimiento de objetivos para indicar que termino de abrir correctamente el proyecto y está listo para usarse, esto puede tardar varios segundos dependiendo de la velocidad de la PC:

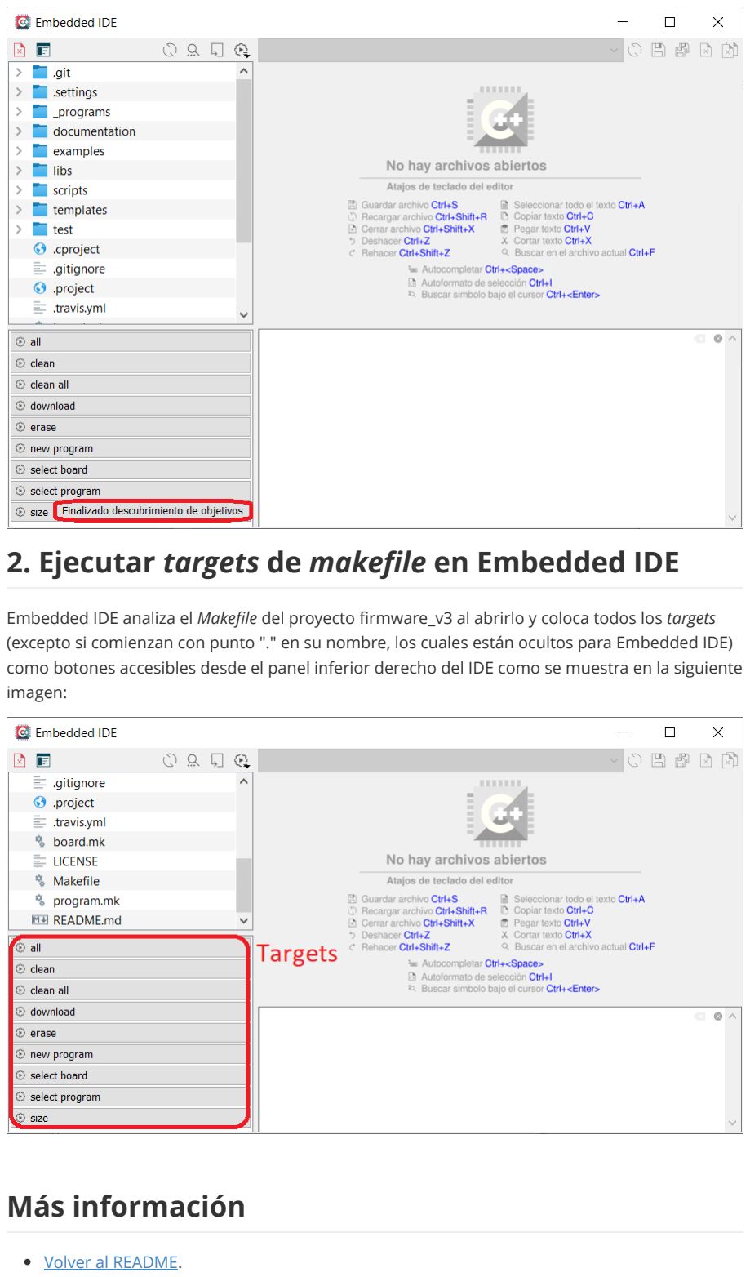
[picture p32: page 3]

# 2. Ejecutar targets de makefile en Embedded IDE

Embedded IDE analiza el Makefile del proyecto firmware_v3 al abrirlo y coloca todos los targets (excepto si comienzan con punto "." en su nombre, los cuales están ocultos para Embedded IDE) como botones accesibles desde el panel inferior derecho del IDE como se muestra en la siguiente imagen:

# Más información

Volver al README.

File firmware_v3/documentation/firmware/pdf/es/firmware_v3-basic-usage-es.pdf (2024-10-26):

# Índice

Utilización básica de firmware_v3
1. Conceptos básicos
2. Flujo básico de trabajo con firmware_v3
2.1. Programas existentes dentro del proyecto firmware_v3
2.1.1. Seleccionar board a utilizar dentro del proyecto firmware_v3
2.1.2. Seleccionar programa a utilizar dentro del proyecto firmware_v3
2.1.3. Compilar el programa seleccionado
2.1.4. Descargar el programa seleccionado a la board seleccionada
2.2. Creación de programas y bibliotecas
2.2.1. Crear un nuevo programa dentro del proyecto firmware_v3
2.2.2. Crear un nuevo módulo de biblioteca dentro del proyecto firmware_v3
3. Lista completa de Targets disponibles

# Utilización básica de firmware_v3

# 1. Conceptos básicos

firmware_v3 es un proyecto en base a makefile (https://www.ecured.cu/Makefile) que actúa como framework para el desarrollo de firmware para sistemas embebidos en lenguajes C/C++.
El makefile posee una serie de targets invocables con make, los cuales permiten: compilar el programa, descargar el programa a la plataforma, etc.
Para los IDEs, firmware_v3 se comporta como un único proyecto, sin embargo está compuesto por múltiples programas para compilar y descargar a las plataformas.

# 2. Flujo básico de trabajo con firmware_v3

## 2.1. Programas existentes dentro del proyecto firmware_v3

Este flujo de trabajo propuesto es válido tanto para los programas de ejemplo provistos, como para programas creados previamente por el usuario en firmware_v3.
Los pasos a seguir son:
1. Seleccionar plataforma de hardware (board) a utilizar dentro del proyecto firmware_v3.
2. Seleccionar programa a utilizar dentro del proyecto firmware_v3.
3. Compilar el programa seleccionado.
4. Descargar el programa seleccionado a la plataforma de hardware (board) seleccionada.

Tanto seleccionar el programa como la plataforma de hardware a utilizar se puede realizar de manera manual (editando archivos de texto) o mediante el uso de la interfaz gráfica (requiere el programa Zenity).
Nota: Si instaló el paquete de software provisto (CIAA Software) (https://github.com/epernia/software/) o tiene Linux Ubuntu 18.04 o superior ya tiene disponible Zenity.

### 2.1.1. Seleccionar plataforma de hardware (board) a utilizar dentro del proyecto firmware_v3

De forma manual

Para seleccionar la board de forma manual se debe:

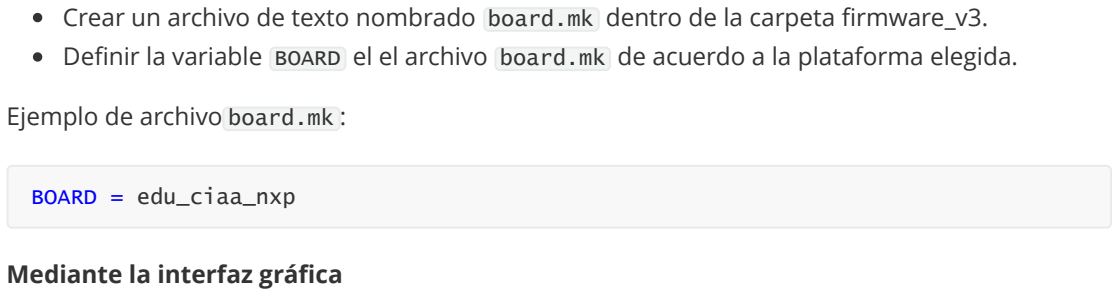
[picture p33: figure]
Ejemplo de archivo board.mk :; Mediante la interfaz gráfica; BOARD = edu_ciaa_nxp

Crear un archivo de texto nombrado board.mk dentro de la carpeta firmware_v3. Definir la variable BOARD el el archivo board.mk de acuerdo a la plataforma elegida.

Se realiza utilizando el target del Makefile de firmware_v3 select_board mediante el comando:

make select_board
El cual lanza un menú en pantalla que presenta las posibles plataformas de hardware disponibles:

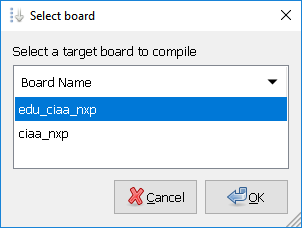
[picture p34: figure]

Al seleccionar una de ellas y presionar OK se crea automáticamente un archivo de texto nombrado board.mk dentro de la carpeta de firmware_v3 que contiene el nombre de la plataforma de hardware seleccionada.

### 2.1.2. Seleccionar programa a utilizar dentro del proyecto firmware_v3

De forma manual

Para seleccionar la el programa a utilizar (para compilar, descargar o limpiar) se debe:

Crear un archivo de texto nombrado program.mk dentro de la carpeta firmware_v3. Definir en el archivo program.mk las variables PROGRAM_NAME y PROGRAM_PATH de acuerdo a l programa que se desea utilizar (PROGRAM_PATH es relativa a la carpeta de firmware_v3, dejar vacía esa variable si el programa está en la carpeta firmware_v3.

Con este archivo se selecciona el programa nombrado app (el nombre de la carpeta que contiene los archivos del programa le da nombre al mismo) dentro de la ruta firmware_v3/examples/c.

Mediante la interfaz gráfica

Se realiza utilizando el target del Makefile de firmware_v3 select_program mediante el comando:

make select_program
Que lanza un menú en pantalla que permite elegir la carpeta del programa a utilizar:


Al seleccionar la carpeta del programa deseado y presionar OK se crea automáticamente un archivo de texto nombrado program.mk dentro de la carpeta de firmware_v3. En la imagen anterior se ve que se selecciona el programa blinky.
Nota: Procure no entrar en la carpeta del programa elegido. Simplemente seleccione la carpeta del programa y presione Ok sin entrar en la carpeta del mismo si no no se ejecutará correctamente este comando.

### 2.1.3. Compilar el programa seleccionado

Se realiza utilizando el target del Makefile de firmware_v3 all mediante el comando:

make all
o simplemente:

make
ya que es el target por defecto.
De esta forma se inicia la compilación cruzada del programa seleccionado para la plataforma seleccionada junto a todas sus dependencias.

### 2.1.4. Descargar el programa seleccionado a la plataforma de hardware (board) seleccionada

Se realiza utilizando el target del Makefile de firmware_v3 download mediante el comando:

make download
Se abre OpenOCD y se descarga el programa a la memoria de la plataforma de hardware seleccionada.

## 2.2. Creación de programas y bibliotecas

### 2.2.1. Crear un nuevo programa dentro del proyecto firmware_v3

Un programa puede generase manualmente o mediante la interfaz gráfica.

De forma manual

Cada programa consiste en una carpeta (cuyo nombre no puede contener espacios ni caracteres latinos) que incluye al menos 2 subcarpetas, una nombrada src (aquí se ponen los archivos de código fuente, .c, .cpp, .ino o .s), y otra nombrada inc (aquí se ponen los archivos de cabeceras

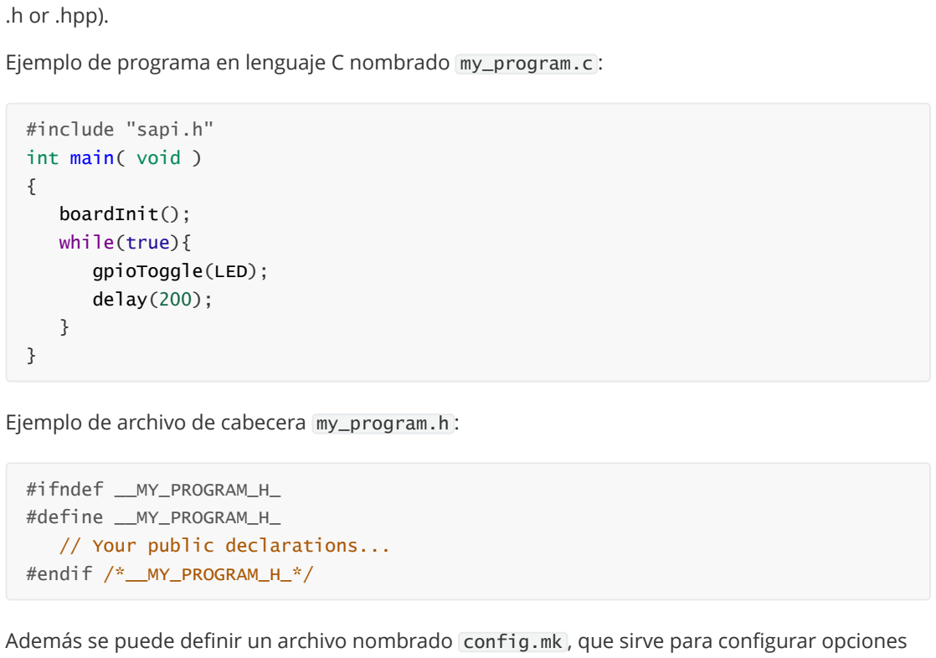
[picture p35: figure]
.h or .hpp).; #include "sapi.h"; int main( void ); boardInit();; while(true){; gpioToggle(LED);; delay(200);; #ifndef __MY_PROGRAM_H_; #define __MY_PROGRAM_H_; // Your public declarations... #endif /*__MY_PROGRAM_H_*/

Ejemplo de programa en lenguaje C nombrado my_program.c :

Ejemplo de archivo de cabecera my_program.h :

Además se puede definir un archivo nombrado config.mk , que sirve para configurar opciones de compilación y bibliotecas a incluir en el programa.

Ejemplo de config.mk con valores por defecto:

Nota: Si no define este archivo se tomarán dichos valores por defecto. Finalmente, la estructura completa de un programa es:

# Compilation and libraries default values

# Compile options

VERBOSE=n
OPT=g
USE_NANO=y
USE_LTO=n
SEMIHOST=n
USE_FPU=y
ENFORCE_NOGPL=n

# Libraries

USE_LPCOPEN=y
USE_SAPI=y

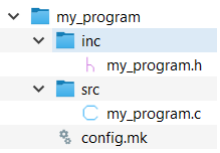
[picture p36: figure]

Nota: el archivo my_program.h es opcional.

Mediante la interfaz gráfica

Se realiza utilizando el target del Makefile de firmware_v3 new_program mediante el comando:

make new_program
que inicia una ventana donde se puede elegir:
El nombre del programa (requerido).
Su versión (opcional).
La plantilla de programa a utilizar (requerido).

Ejemplo:

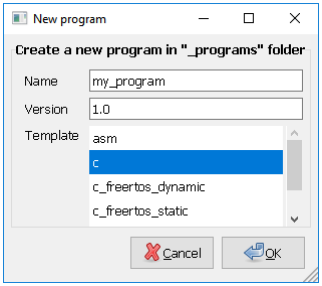
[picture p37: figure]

Note: La primera vez pedirá al usuario que complete las preferencias de usuario:

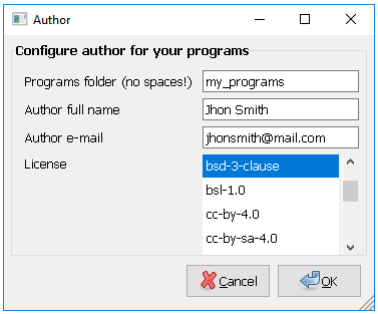
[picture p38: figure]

Estas preferencias de usuario incluyen:

Carpeta donde se guardarán los programas generados (sin espacios o caracteres latinos, requerido).
Nombre completo del autor (requerido).
Mail del autor (requerido).
Licencia del programa.

Todos son campos requeridos.
Las preferencias definidas se guardan en el archivo:

firmware_v3/scripts/user/user_preferences.cfg
que se puede borrar o editar manualmente si se desean cambiar las mismas.

### 2.2.2. Crear un nuevo módulo de biblioteca dentro del proyecto firmware_v3

Bibliotecas globales

La carpeta libs incluye bibliotecas que pueden utilizarse desde cualquier programa (bibliotecas globales).

El Makefile permite compilar dos tipos de bibliotecas:

Biblioteca simple. Consiste en una carpeta (con nombre sin espacios, ni caracteres latinos) que en su interior incluye dos carpetas, una nombrada src (aquí se ponen los archivos de código fuente, .c, .cpp, .ino o .s), y otra nombrada inc (aquí se ponen los archivos de cabeceras .h or .hpp). Esta clase de bibliotecas son compiladas automáticamente por el Makefile.
Bibliotecas avanzadas. Consisten en bibliotecas con una estructura compleja de archivos y carpetas, por ejemplo, LibUSB. En este caso se requiere crear un makefile propio de la biblioteca nombrado module.mk . Se puede ver como ejemplo el makefile de la biblioteca dentro de la biblioteca sAPI.
Ejemplo de archivo module.mk de la biblioteca avanzada sAPI:

Bibliotecas locales a un programa

ifeq ($(USE_SAPI),y)

SAPI_BASE=libs/sapi/sapi_v0.5.2

DEFINES+=USE_SAPI

INCLUDES += -I$(SAPI_BASE)/base/inc
INCLUDES += -I$(SAPI_BASE)/soc/core/inc
INCLUDES += -I$(SAPI_BASE)/soc/peripherals/inc
INCLUDES += -I$(SAPI_BASE)/soc/peripherals/usb/device/inc INCLUDES += -I$(SAPI_BASE)/soc/peripherals/usb/host/inc INCLUDES += -I$(SAPI_BASE)/board/inc
INCLUDES += -I$(SAPI_BASE)/abstract_modules/inc

SRC += $(wildcard $(SAPI_BASE)/base/src/*.c)
SRC += $(wildcard $(SAPI_BASE)/soc/core/src/*.c)
SRC += $(wildcard $(SAPI_BASE)/soc/peripherals/src/*.c)
SRC += $(wildcard $(SAPI_BASE)/soc/peripherals/usb/device/src/*.c) SRC += $(wildcard $(SAPI_BASE)/soc/peripherals/usb/host/src/*.c) SRC += $(wildcard $(SAPI_BASE)/board/src/*.c)
SRC += $(wildcard $(SAPI_BASE)/abstract_modules/src/*.c)

# External Peripherals

include $(SAPI_BASE)/external_peripherals/module.mk

endif

Para las bibliotecas dentro de un programa de usuario específico tenemos también las mismas dos opciones, bibliotecas básicas y avanzadas. En ambos casos se crean de la misma forma que las bibliotecas globales. El único cambio es que en el caso de ser una biblioteca básica se guardan los archivos que la componen en las subcarpetas inc y src dentro de la carpeta del programa a la cual pertenece, y en el caso de una biblioteca avanzada, se deben agregar al archivo config.mk del programa las rutas (paths) de los archivos de esta nueva biblioteca.

# 3. Lista completa de Targets disponibles

A continuación se listan todos los targets disponibles en firmware_v3:
Targets principales

all Compilar programa seleccionado.
clean Eliminar archivos de compilaciones previas (remueve la carpeta out dentro del programa seleccionado). Es necesario ejecutarlo sobre le programa seleccionado al cambiar opciones de compilación del programa (archivo config.mk) o al cambiar la plataforma de hardware (board) para la cual se compilará el programa.
clean_all Eliminar archivos de compilaciones previas de todos los programas dentro de la carpeta firmware_v3.
download Descarga el programa seleccionado a la board seleccionada.
erase Borra la flash de la board seleccionada. Es necesario resetear la plataforma luego de aplicarlo.
new_program Permite gráficamente crear un nuevo programa dentro de la carpeta seleccionada por el usuario (la primera vez se pide el nombre de la carpeta donde se guardaran los programas y se crea dentro de la carpeta firmware_v3).
select_board Permite elegir gráficamente la plataforma de hardware (board) para la cual se compilará el programa.
select_program Permite elegir gráficamente el programa a utilizar (compilar, descargar, limpiar, etc.).
size Muestra la ocupación del programa compilado para el programa seleccionado en las distintas áreas de memoria de la board seleccionada.
Otros targets
debug Depurar con Embedded IDE (usa los targets .debug y .run, se utiliza con Embedded IDE y junto a gdbFront. Advertencia: es una característica en desarrollo. (https://github.com/martinribelotta/embedded-ide)
.info Información de la compilación.
.axf_to_bin Convertir archivo .axf a .bin.
.elf_to_bin Convertir archivo .elf a .bin.
.debug Depurar con Embedded IDE (debug).
.run Depurar con Embedded IDE (run).
.hardware_test Ejecutar tests en hardware.
.test_build_all Ejecuta un test que comprueba que todos los programas compilen de forma correcta. Advertencia: que compilen no significa que funcionen de la forma esperada.
.enforce_no_gpl : Chequea que no haya código (L)GPL en tu proyecto.

# Más información

Volver al README.

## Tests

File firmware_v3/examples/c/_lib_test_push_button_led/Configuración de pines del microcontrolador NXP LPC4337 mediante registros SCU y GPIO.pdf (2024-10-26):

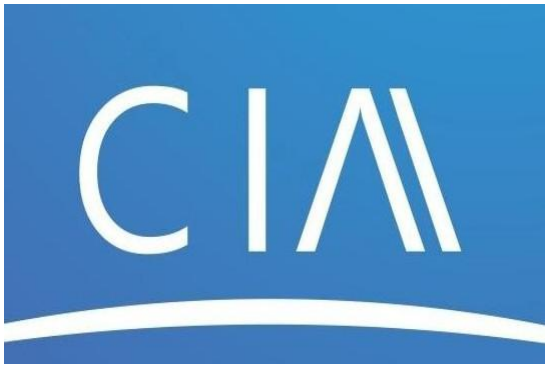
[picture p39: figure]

### Configuración de pines del microcontrolador NXP LPC4337 mediante registros SCU y GPIO

- Mg. Ing. Eric Pernia.
- Ing. Ian Olivieri

http://www.proyecto-ciaa.com.ar/

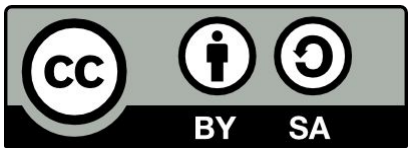
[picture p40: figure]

“Configuración de pines del microcontrolador NXP LPC4337 mediante registros SCU y GPIO” Por Esp. Ing. Eric Pernia e Ing. Ian Olivieri, se distribuye bajo una Licencia Creative Commons Atribución-CompartirIgual 4.0 Internacional. (http://creativecommons.org/licenses/by-sa/4.0/)

## Licencia

1. Diagrama en bloques de un pin.
2. Reconocer los pines del microcontrolador (MCU).
3. System Control Unit (SCU).
4. Registro SCU de configuración de pin SFSPN_M.
5. Configuración de pines para LED1 y TEC1.
6. SCU - Resumen de configuración para GPIO.
7. Registro de configuración de dirección de GPIO.

### 8. Configuración de dirección de pines para LED1 y

TEC1.

### 9. Funciones LPCOpen de GPIO para leer y escribir

pines.
10. Ejemplo Pulsador ---> LED.

## Temario

## Diagrama en bloques de un pin

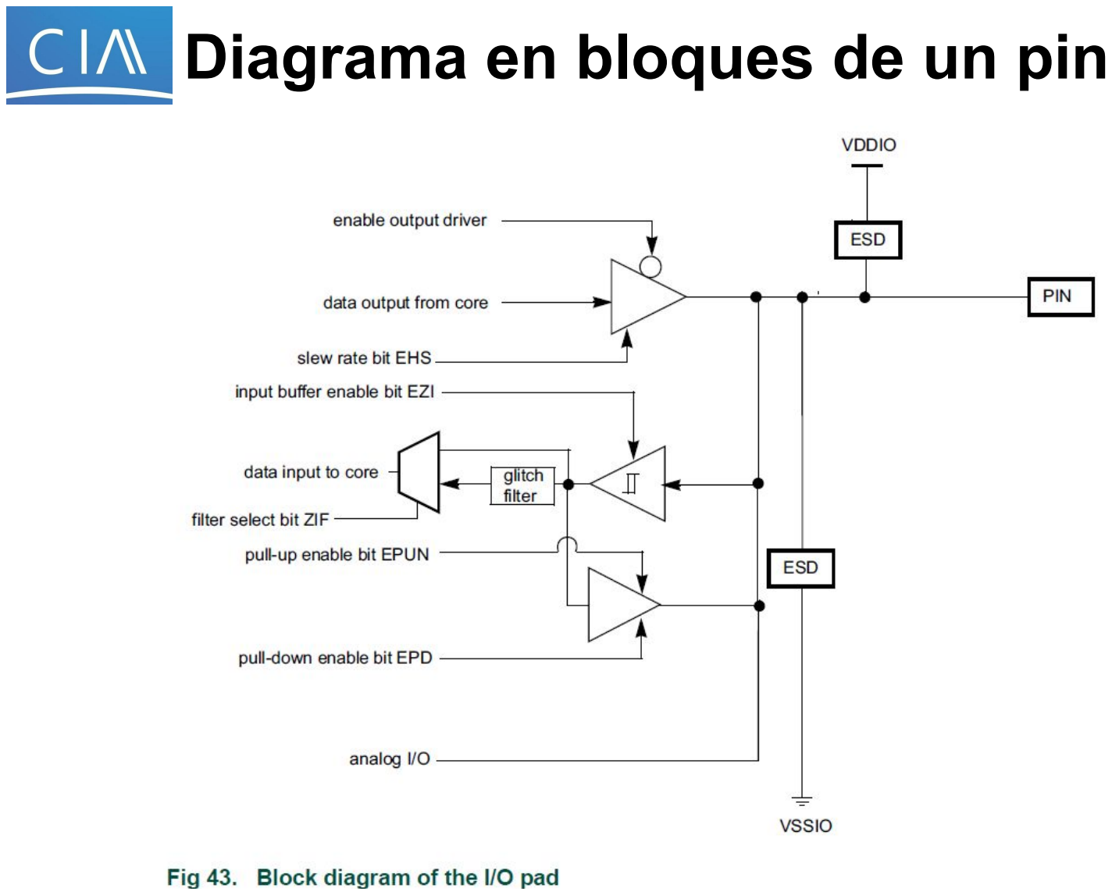
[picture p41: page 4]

Supongamos que queremos configurar en la EDU-CIAA-NXP los pines conectados a LED1 como salida digital y TEC1 como entrada digital.

Si miramos el archivo de asignación de pines de la EDU-CIAA-NXP veremos que:

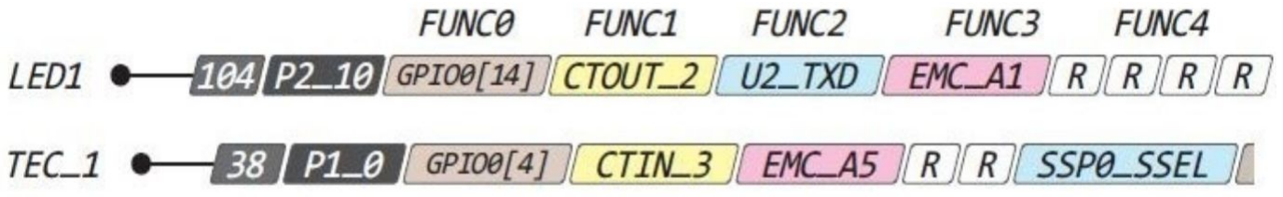
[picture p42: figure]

- El diodo LED, LED1, está conectado al Pin N° 104 del microcontrolador.
- El pulsador, TEC1, está conectado al Pin N° 38 del microcontrolador.

## Reconocer los pines del MCU

Para configurar un pin en el microcontrolador LPC4337 debemos conocer un subsistema encargado de la configuración de los pines el cual se llama System Control Unit (SCU).

Este se encarga de configurar a qué periférico interno se conecta un pin físico del chip (FUNC), además de otras configuraciones eléctricas de los mismos (pull resistors, glich filter, input buffer, etc.).

De esta forma, existe un registro de 32 bits asociado a cada pin donde configuramos al mismo nombrado:

SFSPN_M, con N número de port y M número de pin.

## System Control Unit (SCU)

Los parámetros port y pin para los registros SCU pueden ser obtenidos del manual de usuario del LPC4337 (página 242 de 1433). En esta presentación se utiliza como alternativa el documento asignación de pines de la EDU-CIAA-NXP que tiene un resumen de los pines de la plataforma.

Las funciones pueden ser FUNC0, FUNC1,... FUNC7 y su elección depende de como se requiera utilizar el pin.

## System Control Unit (SCU)

Si miramos nuevamente el archivo de asignación de pines de la EDU-CIAA-NXP veremos que:

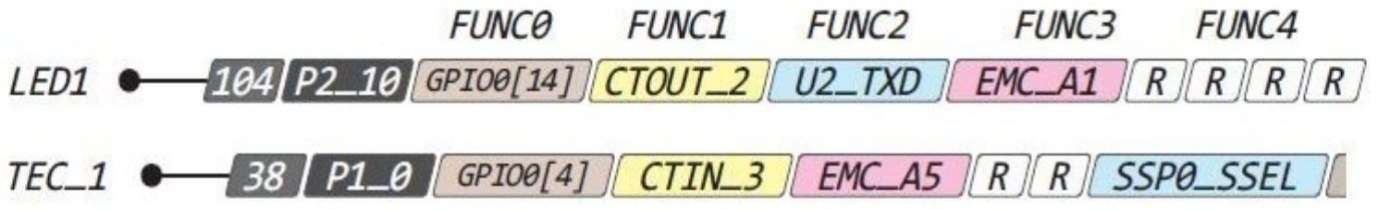
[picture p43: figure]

- LED1 (pin N° 104 del MCU) corresponde a P2_10 (Port = 2 y Pin = 10). Entonces se configura mediante el registro SFSP2_10.
- TEC1 (pin N° 104 del MCU) corresponde a P1_0 (Port = 1 y Pin = 0). Entonces se configura mediante el registro SFSP1_0.

También se ve que para estos pines físicos, la función que corresponde a GPIO es la FUNC0, que corresponde a los primeros bits de un cierto registro SFSPN_M como veremos a continuación.

## System Control Unit (SCU)

Registro SCU de configuración de pin SFSPN_M

Bits MODE del registro SFSPN_M para configurar a qué periférico interno se conecta un pin físico del MCU.

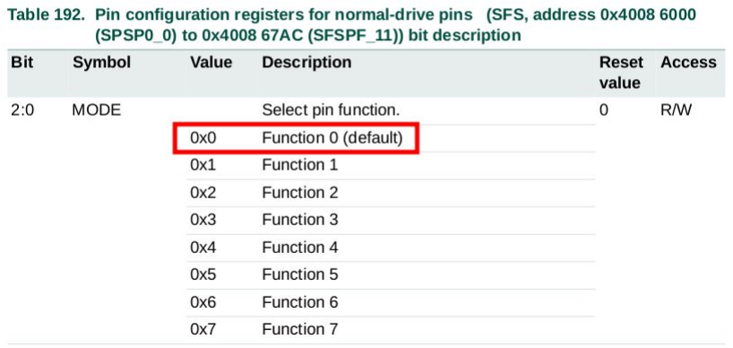
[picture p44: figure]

Registro SCU de configuración de pin SFSPN_M

Bits EPD y EPUN del registro SFSPN_M para configurar resistencias de Pull-down y Pull-Up conectadas a un pin físico del MCU.

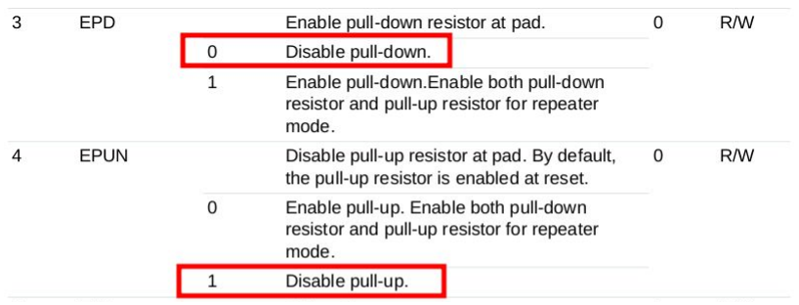
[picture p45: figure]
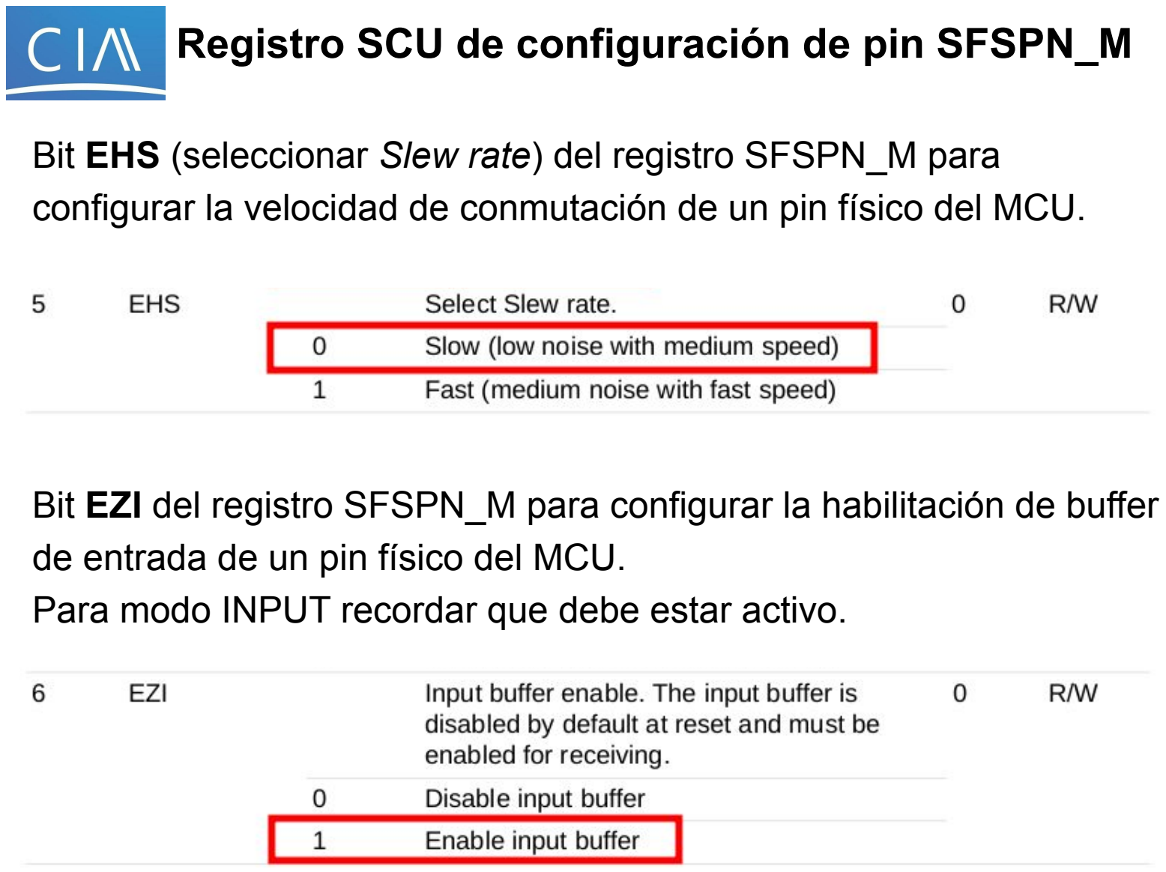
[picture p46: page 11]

Registro SCU de configuración de pin SFSPN_M

Bit EHS (seleccionar Slew rate) del registro SFSPN_M para configurar la velocidad de conmutación de un pin físico del MCU.

Bit EZI del registro SFSPN_M para configurar la habilitación de buffer de entrada de un pin físico del MCU.
Para modo INPUT recordar que debe estar activo.

Registro SCU de configuración de pin SFSPN_M

Bit ZIF del registro SFSPN_M para configurar la habilitación de filtro de ruido de entrada de un pin físico del MCU.

Las funciones de biblioteca que nos provee el fabricante (LPC Open) para realizar la configuración de SCU se encuentran en la biblioteca scu_18xx_43xx.h. En particular, utilizaremos la función:

void Chip_SCU_PinMux( uint8_t port, uint8_t pin, uint16_t mode, uint8_t func );

### Configuración de pines para LED1 y TEC1

A continuación veremos cómo se configuran ambos pines físicos (LED1 y TEC1) para que se conecten a sus respectivas funcionalidades de GPIO.

Diodo LED: | LED1 <---> P2_10, GPIO0[14], | FUNC0
Pulsador: | TEC1 <---> P1_0, | GPIO0[4], | FUNC0

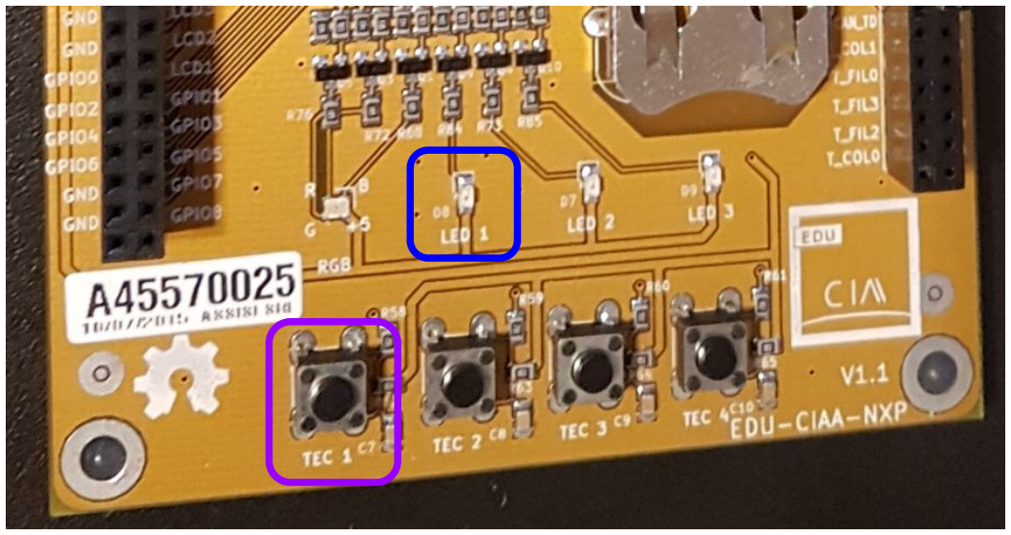
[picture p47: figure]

### Configuración de pines para LED1 y TEC1

Diodo LED: LED1 <---> P2_10, GPIO0[14], FUNC0

Configurar que el pin P2_10 se conecte internamente a GPIO0[14] mediante registro SFSP2_10:

Dirección del registro SFSP2_10 = SCU_BASE + SFSP2_10 (offset)
= 0x40086000 + 0x128 = 0x40086128

Valor de configuración a guardar en esa dirección =
= SCU_MODE_INACT | SCU_MODE_FUNC0
= (0x2 << 3) | 0x0 = 0x00000010

Usando LPCopen:

Chip_SCU_PinMux( 2, 10, SCU_MODE_INACT, SCU_MODE_FUNC0 );

### Configuración de pines para LED1 y TEC1

Pulsador: | TEC1 <---> P1_0, | GPIO0[4], | FUNC0

Configurar que el pin P1_0 se conecte internamente a GPIO0[4] mediante registro SFSP1_0:

Dirección del registro SFSP1_0 = SCU_BASE + SFSP1_0(offset)
= 0x40086000 + 0x080 = 0x40086080

Valor de configuración a guardar en esa dirección =
= SCU_MODE_INACT | SCU_MODE_INBUFF_EN | SCU_MODE_FUNC0
= (0x2 << 3) | (0x1 << 6) | 0x0 = 0x00000090

Usando LPCopen:

Chip_SCU_PinMux( 1, 0, SCU_MODE_INACT | SCU_MODE_INBUFF_EN,
SCU_MODE_FUNC0 );

En LPC4337 Para la funcionalidad de GPIO vamos a ver que se encuentran (si el pin soporta) en los modos FUNC0 o FUNC4. Además:

- Para el modo OUTPUT: SCU_MODE_INACT
- Para el modo INPUT (sin pull-up ni pull-down):
SCU_MODE_INACT | SCU_MODE_INBUFF_EN
- Para el modo INPUT_PULLUP (sólo con pull-up):
SCU_MODE_PULLUP | SCU_MODE_INBUFF_EN
- Para el modo INPUT_PULLDOWN (sólo con pull-down):
SCU_MODE_PULLDOWN | SCU_MODE_INBUFF_EN
- Para el modo INPUT_REPEATER (con pull-up y pull-down):
SCU_MODE_REPEATER | SCU_MODE_INBUFF_EN

Opcionalmente se puede agregar a todos: SCU_MODE_ZIF_DIS

Estos datos se encuentran en la página 413 del manual de usuario del LPC4337. Para más información referirse al capítulo 16 y 17 del manual de usuario del LPC4337

### SCU - Resumen de configuración para GPIO

Registro de configuración de dirección de GPIO

Los GPIO (General Purpose Input/Output) son las entradas y salidas digitales del microcontrolador. Los pines con funcionalidad de GPIO se agrupan en puertos y se numeran de la forma GPION[M]. Con N, número de puerto y M, número de pin en el puerto.

NOTA: Aquí, N y M no son los mismos que N y M para los registros de SCU.

Existe por cada puerto (puertos GPIO0 a GPIO7) un registro de dirección donde, mediante cada bit que lo compone, se configuran la dirección cada pin, es decir, si será entrada (0) o salida (1).

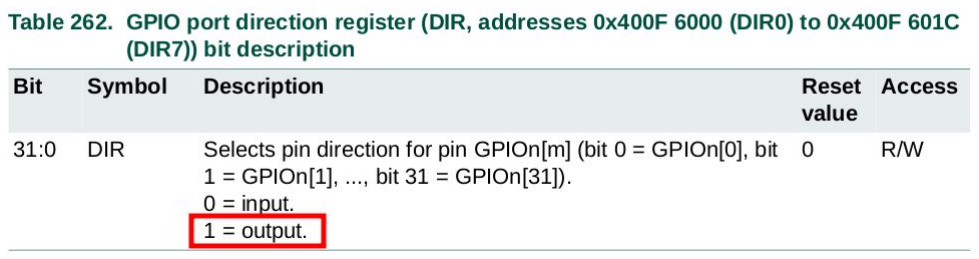
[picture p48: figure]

Las funciones de biblioteca que nos provee el fabricante (LPC Open) para realizar la configuración de GPIO se encuentran en la biblioteca gpio_18xx_43xx.h.

En particular, utilizaremos para configurar un pin como entrada o salida se utiliza la función:

void Chip_GPIO_SetDir( LPC_GPIO_T *pGPIO, uint8_t portNum,
uint32_t bitValue,
uint8_t out );

El primer parámetro de esta función (LPC_GPIO_T *pGPIO) equivale a LPC_GPIO_PORT para el LPC4337.

Aquí, portNum y bitValue no son los mismos que port y pin para el SCU. Son otros parámetros que tienen la forma GPIOportNum[bitValue].

Registro de configuración de dirección de GPIO

Configuración de dirección de pines para LED1 y TEC1

Diodo LED: LED1 <---> P2_10, GPIO0[14], FUNC0

El LED1 corresponde a GPIO0[14], se configurará como salida (1) mediante registro GPIO_PORT0_DIR:

Dirección del registro GPIO_PORT0_DIR =
= GPIO_BASE + GPIO_PORT0_B_OFFSET + GPIO_PORT0_DIR_OFFSET = 0x400F4000 + 0x0 + 0x2000

Valor de configuración a guardar en esa dirección = (1 << 14) = 0x00004000

Usando LPCopen:

Chip_GPIO_SetDir( LPC_GPIO_PORT, 0, (1<<14), 1 );

Configuración de dirección de pines para LED1 y TEC1

Pulsador: | TEC1 <---> P1_0, | GPIO0[4], | FUNC0

TEC1 corresponde a GPIO0[4], se configurará como entrada (0) mediante registro GPIO_PORT0_DIR:

Dirección del registro GPIO_PORT0_DIR =
= GPIO_BASE + GPIO_PORT0_B_OFFSET + GPIO_PORT0_DIR_OFFSET = 0x400F4000 + 0x0 + 0x2000

Valor de configuración a guardar en esa dirección: ~(1 << 4)

Usando LPCopen:

Chip_GPIO_SetDir( LPC_GPIO_PORT, 0, (1<<4), 0 );

Para leer y escribir valores de un pin se utilizan las funciones:

void Chip_GPIO_SetPinState(
LPC_GPIO_T *pGPIO,
uint8_t port,
uint8_t pin,
bool setting
);

bool Chip_GPIO_GetPinState( LPC_GPIO_T *pGPIO,
uint8_t port,
uint8_t pin
);

Para más información referirse al capítulo 19 del manual de usuario del LPC4337

Funciones LPCOpen de GPIO para leer y escribir pines

Hasta aquí tenemos configurados ambos pines LED1 y TEC1 como salida y entrada, respectivamente, ya sea escribiendo registros, o bien, utilizando la biblioteca LPCopen.

Solo nos resta hacer un pequeño programa que lea el valor de TEC1 y lo refleje en LED1, que usando LPCopen es...

## Ejemplo Pulsador ---> LED

#include <chip.h>

#define OUTPUT | 1

#define INPUT | 0

#define ON | 1

#define OFF | 0

int main( void )
{
// Diodo LED: LED1 <---> P2_10, GPIO0[14] ----------------------------------Chip_SCU_PinMux( 2, 10, SCU_MODE_INACT, SCU_MODE_FUNC0 ); Chip_GPIO_SetDir( LPC_GPIO_PORT, 0, (1<<14), OUTPUT ); Chip_GPIO_SetPinState( LPC_GPIO_PORT, 0, 14, OFF );

// Pulsador: TEC1 <---> P1_0, GPIO0[4] -------------------------------------
Chip_SCU_PinMux( 1, 0, SCU_MODE_INACT | SCU_MODE_INBUFF_EN, SCU_MODE_FUNC0 );
Chip_GPIO_SetDir( LPC_GPIO_PORT, 0, (1<<4), INPUT );

while( 1 ) {
// !(TEC1) --> LED1
// Negado (!) porque el pulsador esta en 1 por defecto y al presionar da 0 uint8_t value = Chip_GPIO_GetPinState( LPC_GPIO_PORT, 0, 4 ); Chip_GPIO_SetPinState( LPC_GPIO_PORT, 0, 14, !value );
}
return 0;
}

## Ejemplo Pulsador ---> LED

- Manual de usuario del microcontrolador NXP LPC4337.
- Archivos de LPCOpen.
- Web del proyecto CIAA.

## Bibliografía

# Consultas:

ericpernia@gmail.com

# ¡Muchas gracias!

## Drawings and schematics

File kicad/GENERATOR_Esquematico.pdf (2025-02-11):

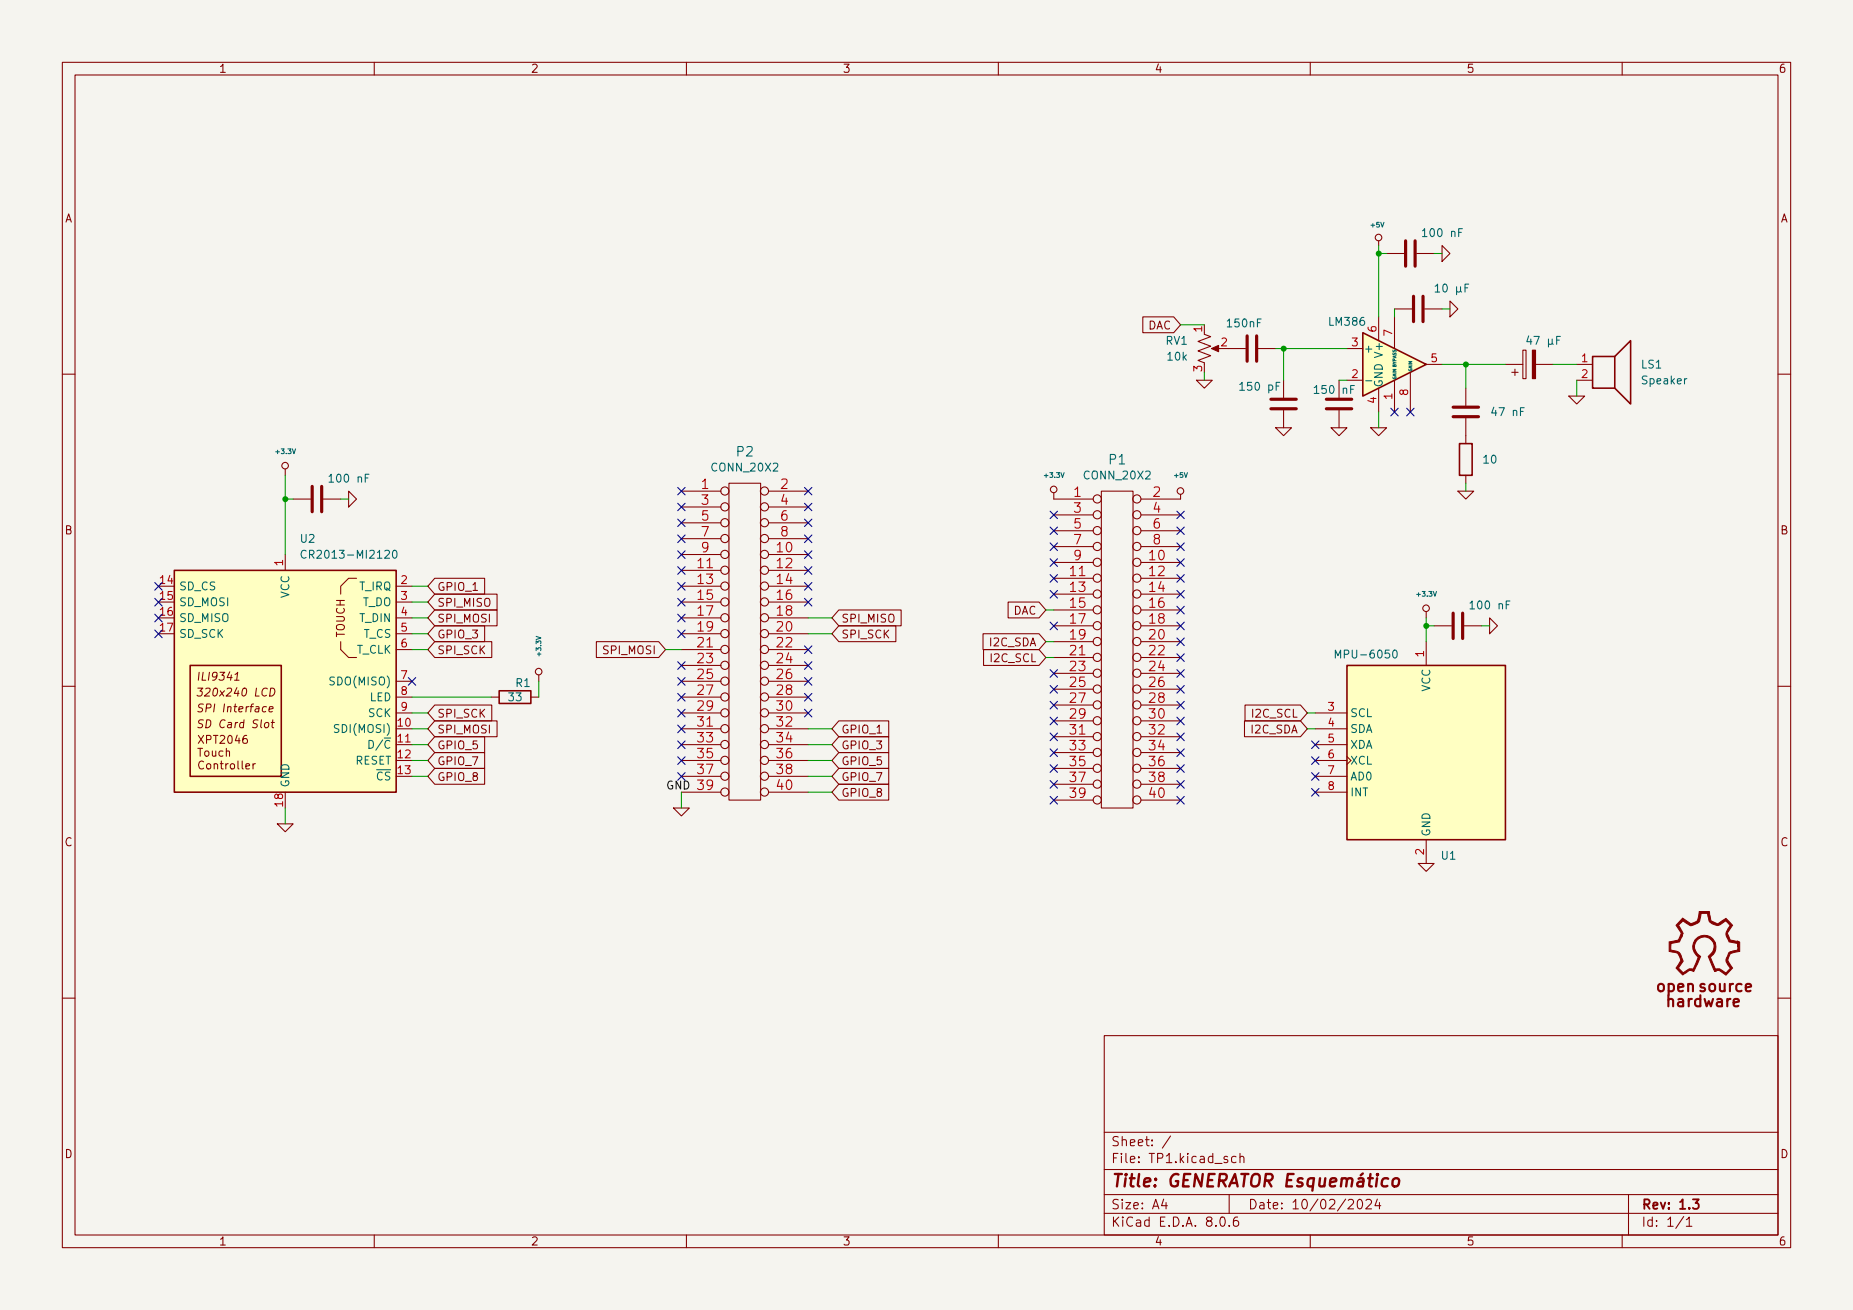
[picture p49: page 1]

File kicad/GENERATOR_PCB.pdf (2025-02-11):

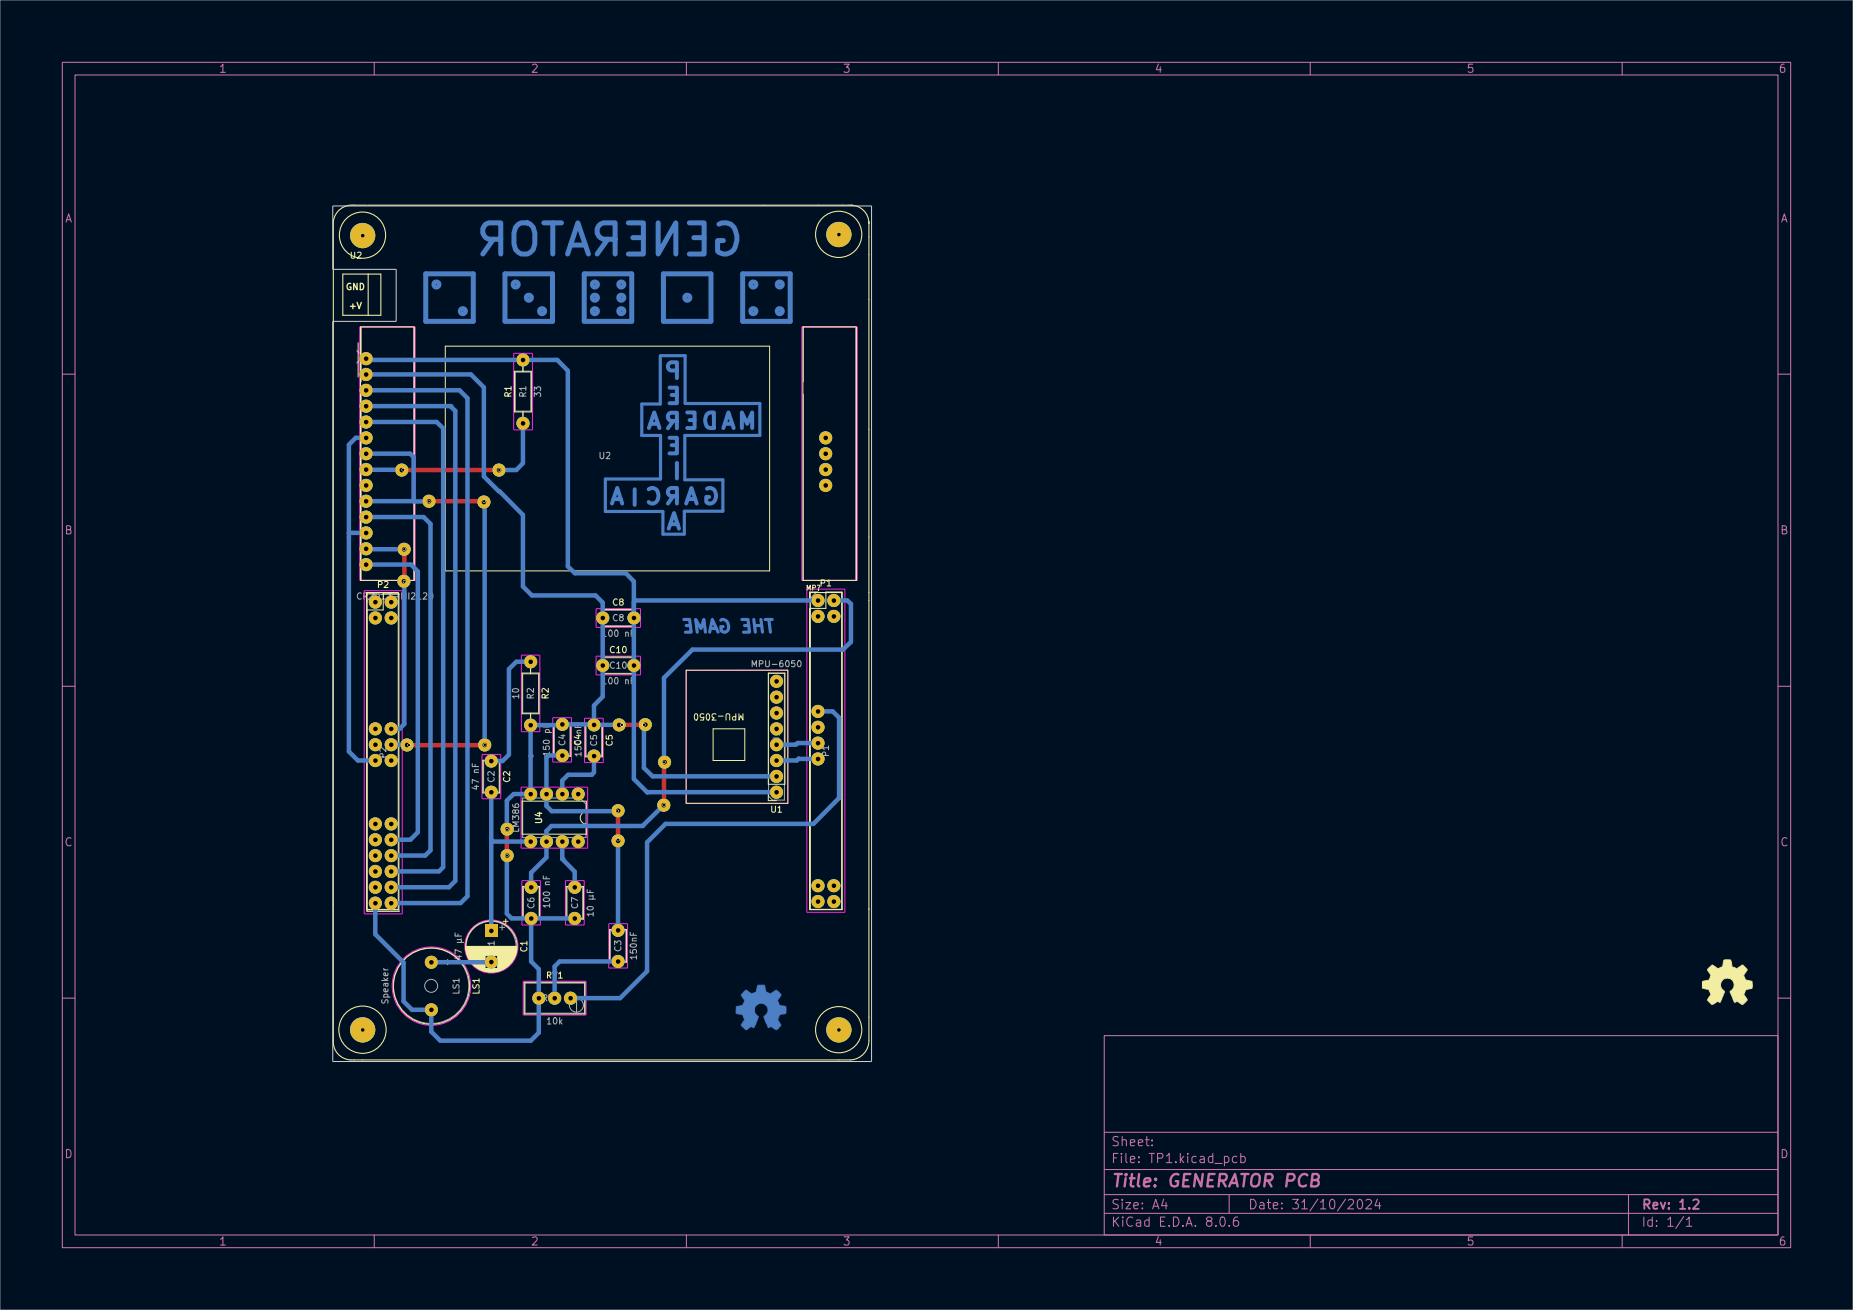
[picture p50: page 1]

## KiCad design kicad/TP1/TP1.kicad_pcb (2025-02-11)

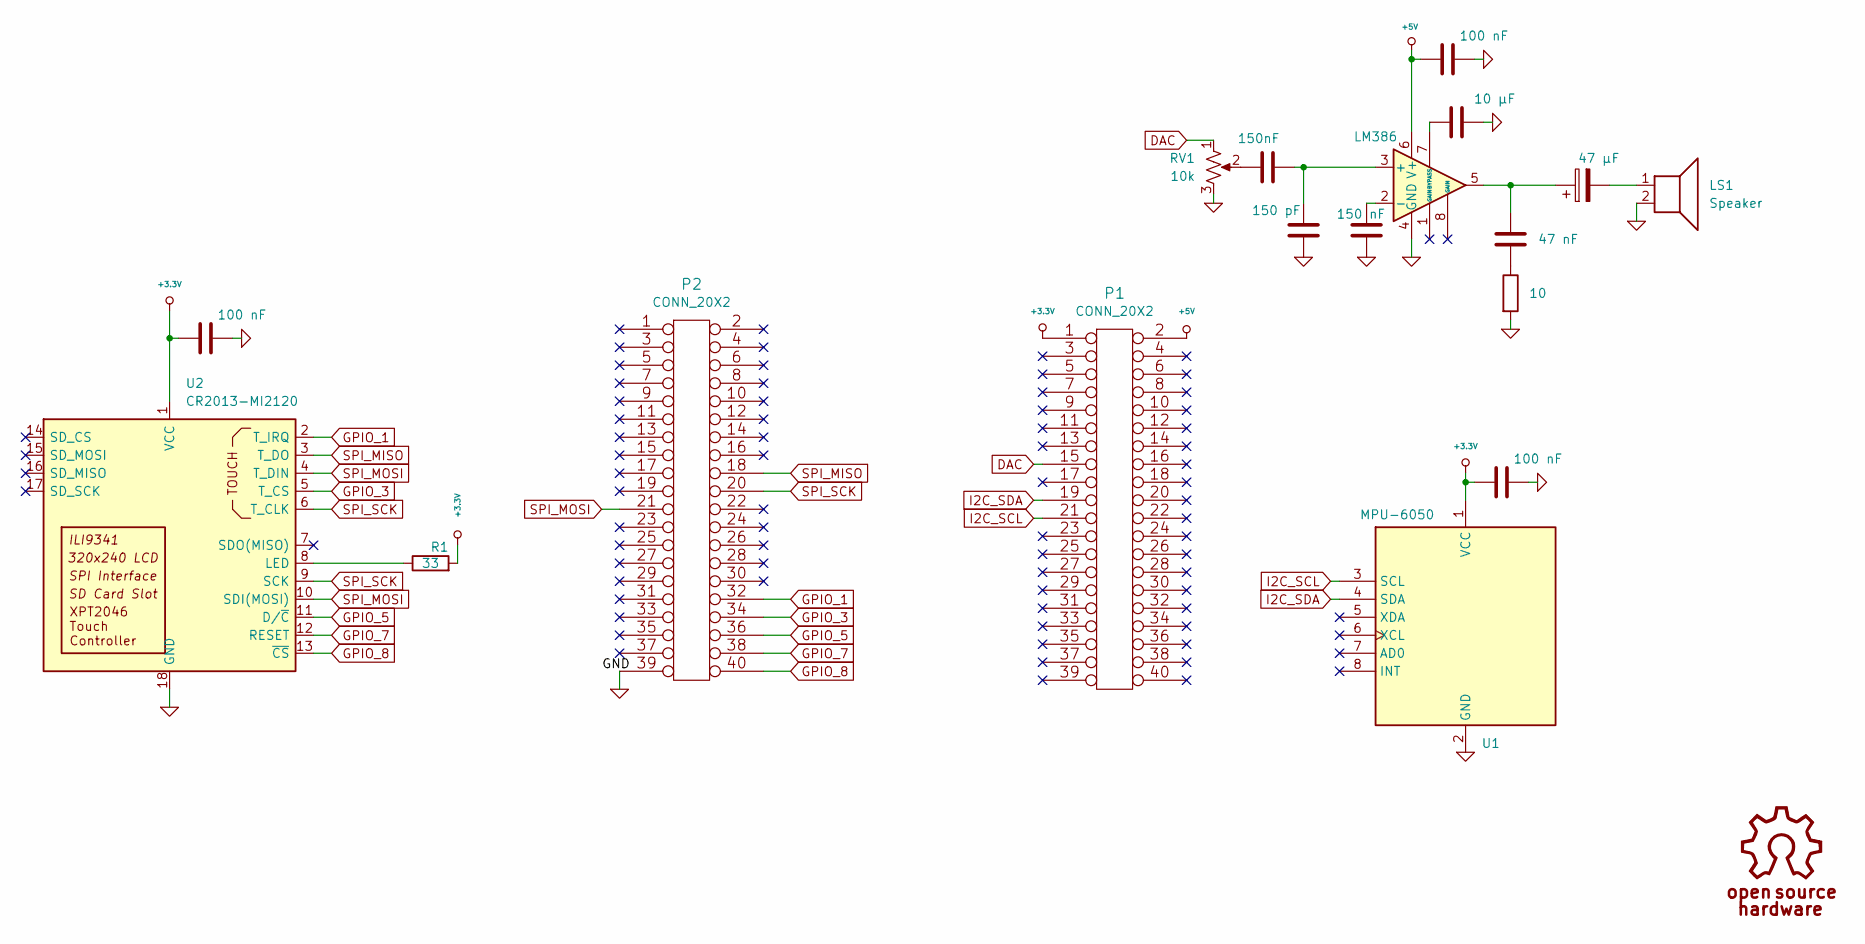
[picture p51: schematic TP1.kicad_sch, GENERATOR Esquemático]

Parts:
C1: 47 μF; CP_Radial_D8.0mm_P5.00mm
C2: 47 nF; C_Disc_D5.0mm_W2.5mm_P5.00mm
C3: 150nF; C_Disc_D5.0mm_W2.5mm_P5.00mm
C4: 150 pF; C_Disc_D5.0mm_W2.5mm_P5.00mm
C5: 150 nF; C_Disc_D5.0mm_W2.5mm_P5.00mm
C6, C8, C10: 100 nF; C_Disc_D5.0mm_W2.5mm_P5.00mm
C7: 10 μF; C_Disc_D5.0mm_W2.5mm_P5.00mm
LS1: Speaker; Buzzer_12x9.5RM7.6
P1, P2: CONN_20X2; PinSocket_2x20_P2.54mm_Vertical
R1: 33; R_Axial_DIN0207_L6.3mm_D2.5mm_P10.16mm_Horizontal
R2: 10; R_Axial_DIN0207_L6.3mm_D2.5mm_P10.16mm_Horizontal
RV1: 10k; Potentiometer_Piher_PT-6-V_Vertical
U1: MPU-6050; MPU-3050
U2: CR2013-MI2120; ILI_footprint
U4: LM386; DIP-8_W7.62mm

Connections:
+3.3V: C8.2, C10.2, P1.1, R1.2, U1.1 (VCC), U2.1 (VCC)
+5V: C6.2, P1.2, U4.6 (V+)
DAC: P1.15, RV1.1
GND: C4.1, C5.1, C6.1, C7.1, C8.1, C10.1, LS1.2, P2.39, R2.2, RV1.3, U1.2 (GND), U2.18 (GND), U4.4 (GND)
GPIO_1: P2.32, U2.2 (T_IRQ)
GPIO_3: P2.34, U2.5 (T_CS)
GPIO_5: P2.36, U2.11 (D/~C)
GPIO_7: P2.38, U2.12 (RESET)
GPIO_8: P2.40, U2.13 (~CS)
I2C_SCL: P1.21, U1.3 (SCL)
I2C_SDA: P1.19, U1.4 (SDA)
unnamed: C1.1, C2.2, U4.5
unnamed: C1.2, LS1.1
unnamed: C2.1, R2.1
unnamed: C3.1, RV1.2
unnamed: R1.1, U2.8 (LED)
unnamed: C3.2, C4.2, U4.3 (+)
unnamed: C5.2, U4.2 (-)
unnamed: C7.2, U4.7 (BYPASS)
SPI_MISO: P2.18, U2.3 (T_DO)
SPI_MOSI: P2.21, U2.4 (T_DIN), U2.10 (SDI(MOSI))
SPI_SCK: P2.20, U2.6 (T_CLK), U2.9 (SCK)

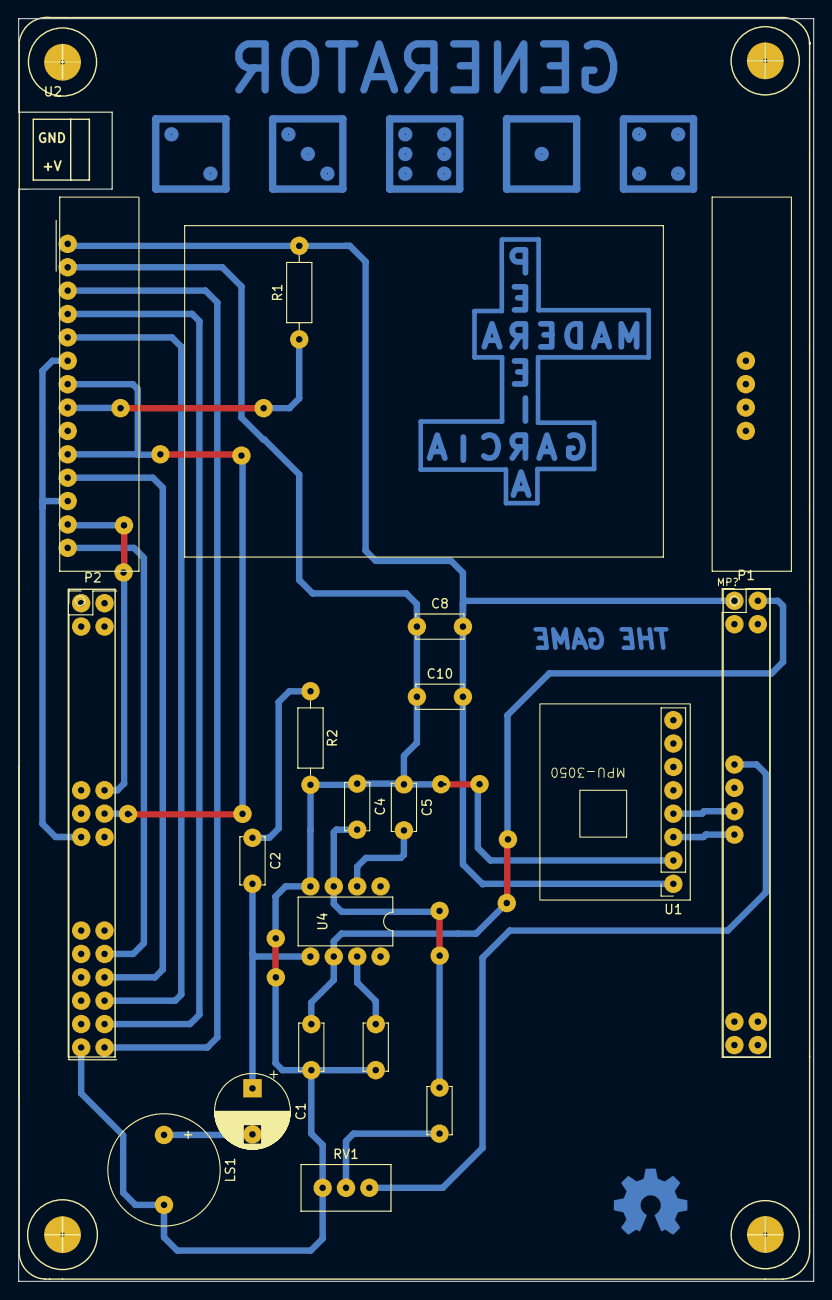
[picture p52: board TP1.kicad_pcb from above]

Board: 2 copper layers, 86.4 x 137.2 mm, 21 parts (0 on the bottom side), 22 nets.

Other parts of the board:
G101, G101#2: Logo_OSHWA
MP?: Plantilla_EDU-CIAA

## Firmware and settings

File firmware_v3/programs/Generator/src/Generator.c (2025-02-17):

#include "../inc/Generator.h"

#include <time.h>
#include "ili9341.h"
#include "sapi.h"
#include "XPT2046_Touchscreen.h"
#include "mpu6050.h"
#include "sonidos.h"

typedef enum {inicio,reposo,sacudiendo,apagado} State;
typedef enum {emayor,emenor,full,poker,generala,nada,j1,j2,j3,j4,j5,j6} Juego;

ili9341_desc_ptr_t display;
TS_Point valPantalla;
State estado,estadoAnt;
int16_t veces=0;
uint8_t dados[5]={0,0,0,0,0};
bool seleccion[5]={false,false,false,false,false};
uint8_t suma;
int16_t seedinicio,seedreposo;
char puntos[12];
Juego tirada;

void inicializacion(void);

void LeerPantalla(void);

Juego CalcularJuego(uint8_t *dados, uint8_t *puntaje);

int main(void) {
    inicializacion();
    // C digo de aplicacion
   delay(150);
   printf("Comenzando ... \r\n");
    while(1){
        //Lecturas de perifericos
        //Aca tiene que ir la lectura del MPU para ver si se esta moviendo

        //MEF de control del dibujito
        switch (estado){
            case inicio:
                if ((estadoAnt!= inicio)){
                    //dibujo de menu principal con nombre de juego y boton de "iniciar"
                    ili9341_spi_init(100000000);

                    ili9341_paintBackground(display, 0);
                    coord_2d_t square_top_left = {110, 70}; // (320-100)/2, (240-100)/2
                    coord_2d_t square_bottom_right = {210, 170};

                    ili9341_set_region(display, square_top_left, square_bottom_right);
                    ili9341_fill_region(display, RED);
                    ili9341_setTextSize(1);
                    ili9341_setTextColor(BLACK, RED);
                    ili9341_setCursor(115, 137);
                    ili9341_printStr(display, "RED");
                    ili9341_setCursor(115, 147);
                    ili9341_printStr(display, "SQUARE");
                    ili9341_setCursor(115, 157);
                    ili9341_printStr(display, "PRODUCTIONS_");

                    ili9341_setTextColor(WHITE, BLACK);
                    ili9341_setCursor(5, 206);
                    ili9341_printStr(display, "GARCIA");
                    ili9341_setCursor(5, 216);
                    ili9341_printStr(display, "MADERA");
                    ili9341_setCursor(5, 226);
                    ili9341_printStr(display, "PEREIRA_");

                    delay_ms(3000);
                    ili9341_paintBackground(display, 0);

                    uint16_t col = YELLOW;
                    ili9341_drawHLine(display, 141, 1, 179 - 141, col);
                    ili9341_drawHLine(display, 137, 2, 183 - 137, col);
                    ili9341_drawHLine(display, 134, 3, 186 - 134, col);
                    ili9341_drawHLine(display, 132, 4, 188 - 132, col);
                    
                    ili9341_drawHLine(display, 124, 8, 196 - 124, col);
                    ili9341_drawHLine(display, 122, 9, 198 - 122, col);
                    ili9341_drawHLine(display, 120, 10, 200 - 120, col);
                    ili9341_drawHLine(display, 119, 11, 201 - 119, col);

                    ili9341_drawHLine(display, 113, 15, 207 - 113, col);
                    ili9341_drawHLine(display, 112, 16, 208 - 112, col);
                    ili9341_drawHLine(display, 111, 17, 209 - 111, col);
                    ili9341_drawHLine(display, 110, 18, 210 - 110, col);

                    ili9341_drawHLine(display, 106, 22, 214 - 106, col);
                    ili9341_drawHLine(display, 105, 23, 215 - 105, col);
                    ili9341_drawHLine(display, 104, 24, 216 - 104, col);
                    ili9341_drawHLine(display, 103, 25, 217 - 103, col);

                    ili9341_drawHLine(display, 100, 29, 220 - 100, col);
                    ili9341_fillRect(display, 99, 30, 221 - 99, 2, col);
                    ili9341_drawHLine(display, 98, 32, 222 - 98, col);

                    col = ORANGE;
                    ili9341_fillRect(display, 95, 36, 225 - 95, 2, col);
                    ili9341_fillRect(display, 94, 38, 226 - 94, 2, col);

                    ili9341_drawHLine(display, 92, 43, 228 - 92, col);
                    ili9341_fillRect(display, 91, 44, 229 - 91, 3, col);

                    ili9341_setTextSize(5);
                    ili9341_setCursor(28, 50);
                    ili9341_setTextColor(0xdaa0, 0);
                    ili9341_printStr(display, "GENERATOR");

                    ili9341_fillRect(display, 89, 93, 231 - 89, 2, col);
                    ili9341_fillRect(display, 90, 95, 230 - 90, 2, col);

                    ili9341_fillRect(display, 92, 100, 228 - 92, 3, col);
                    ili9341_fillRect(display, 93, 103, 227 - 93, 1, col);
                    
                    col = RED;
                    ili9341_fillRect(display, 95, 107, 225 - 95, 2, col);
                    ili9341_fillRect(display, 96, 109, 224 - 96, 2, col);

                    ili9341_fillRect(display, 99, 114, 221 - 99, 1, col);
                    ili9341_fillRect(display, 100, 115, 220 - 100, 2, col);
                    ili9341_fillRect(display, 101, 117, 219 - 101, 1, col);

                    ili9341_fillRect(display, 104, 121, 216 - 104, 1, col);
                    ili9341_fillRect(display, 105, 122, 215 - 105, 1, col);
                    ili9341_fillRect(display, 106, 123, 214 - 106, 1, col);
                    ili9341_fillRect(display, 107, 124, 213 - 107, 1, col);

                    ili9341_fillRect(display, 111, 128, 209 - 111, 1, col);
                    ili9341_fillRect(display, 112, 129, 208 - 112, 1, col);
                    ili9341_fillRect(display, 113, 130, 207 - 113, 1, col);
                    ili9341_fillRect(display, 115, 131, 205 - 115, 1, col);

                    ili9341_fillRect(display, 120, 135, 200 - 120, 1, col);
                    ili9341_fillRect(display, 122, 136, 198 - 122, 2, col);
                    ili9341_fillRect(display, 124, 137, 196 - 124, 2, col);
                    ili9341_fillRect(display, 126, 138, 194 - 126, 2, col);   



                    ili9341_drawRectangle(display, 57, 142, 206, 46, 0xdaa0);
                    ili9341_setTextSize(3);
                    ili9341_setCursor(100, 153);
                    ili9341_setTextColor(0, 0xdaa0);
                    ili9341_printStr(display, "Iniciar");

                    //detalles botón
                    ili9341_drawRectangle(display, 56, 140, 208, 2, 0x8180);
                    ili9341_drawRectangle(display, 55, 141, 2, 48, 0x8180);
                    ili9341_drawRectangle(display, 56, 188, 208, 2, 0x8180);
                    ili9341_drawRectangle(display, 263, 141, 2, 48, 0x8180);

                    
                    ili9341_drawRectangle(display, 64, 147, 30, 2, 0x9820);
                    ili9341_drawRectangle(display, 62, 149, 2, 15, 0x9820);

                    ili9341_drawRectangle(display, 226, 181, 30, 2, 0x9820); //esquina 256, 181
                    ili9341_drawRectangle(display, 256, 166, 2, 15, 0x9820);
                    //

                    estadoAnt = inicio;
                }
                LeerPantalla();
                if (InStart(&valPantalla)){
                    estado = reposo;
                    printf("Cambio de estado \r\n");
                }
                seedinicio++;
            break;
            case reposo:
               if ((estadoAnt != reposo)&&(estadoAnt != sacudiendo)){
                  //dibujar SOLO el fondo y borde de dados
                  ili9341_spi_init(100000000);
                  ili9341_paintBackground(display, 0xc0e6);
                  ili9341_setDadoFondo(0xFFFF);
                  ili9341_setDadoBorde(0);
                  for (int i = 1; i < 6; i++){
                     ili9341_drawDadoBase(display, i);
                  }
                  seedreposo=0;
               }

               seedreposo++;
               
               if (estadoAnt != reposo)
               {
                  if (estadoAnt == sacudiendo)
                  {
                     //Calculo los nuevos valores
                     for (int i = 1; i < 6; i++) if(!seleccion[i-1]){
                        dados[i-1]=(rand()%6+1);
                        
                     }
                  }
                  // Seleccionar todos los dados
                  ili9341_spi_init(100000000);
                  for (int i = 1; i < 6; i++){ 
                     if (dados[i-1]>0) {
                        ili9341_seleccionarDado(display, i, 0);
                        ili9341_drawDadoNumero(display, i, dados[i-1]);
                        seleccion[i-1]=true;
                     } else {
                        ili9341_drawDadoNumero(display, i, dados[i-1]);
                     }
                  }
                  if (dados[0]>0) reproducirDados();

                  tirada=CalcularJuego(dados,&suma);
                  
                  //for (int i = 0; i < 5; i++) suma+=dados[i];
                  //Antes de todo esto para mi vamos a tener que limpiar el fondo porque (sin probarlo)(Uli) para mi reescribe
                  //Imprimir nombre del juego
                  ili9341_setTextSize(3);
                  ili9341_setCursor(135, 30);
                  ili9341_setTextColor(0xFFFF, 0xc0e6);
                  switch (tirada) {
                     case generala:
                        ili9341_printStr(display, "GEN");
                        reproducirVictoria();
                     break;
                     case poker:
                        ili9341_printStr(display, "POK");
                     break;
                     case full:
                        ili9341_printStr(display, "FUL");
                     break;
                     case emayor:
                        ili9341_printStr(display, "EMA");
                     break;
                     case emenor:
                        ili9341_printStr(display, "EME");
                     break;
                     case j1:
                        ili9341_printStr(display, "UNO");
                     break;
                     case j2:
                        ili9341_printStr(display, "DOS");
                     break;
                     case j3:
                        ili9341_printStr(display, "TRE");
                     break;
                     case j4:
                        ili9341_printStr(display, "CUA");
                     break;
                     case j5:
                        ili9341_printStr(display, "CIN");
                     break;
                     case j6:
                        ili9341_printStr(display, "SEI");
                     break;
                     case nada:
                        ili9341_printStr(display, "G0!");
                     break;
                  }
                  //Imprimir puntaje
                  ili9341_setTextSize(5);;
                  ili9341_setCursor(135, 180);
                  //ili9341_printStr(display, "50");
                  sprintf(puntos, "%d", suma);
                  if(suma>0) {
                     if(suma<10) ili9341_printStr(display, "0");
                     ili9341_printStr(display, puntos);
                  }
               }
               
               estadoAnt = reposo;
               LeerPantalla();
               int16_t dado=SelectDado(&valPantalla);
               if(dado && dados[dado-1]>0){
                  //Selecciono/deselecciono el dado
                  //Y dibujo la seleccion
                  if (seleccion[dado-1]) {
                     ili9341_seleccionarDado(display, dado, 0xc0e6);
                     seleccion[dado-1]=false;
                  } else {
                     ili9341_seleccionarDado(display, dado, 0);
                     seleccion[dado-1]=true;
                  }
                  printf("Dado Numero (%d) \r\n");
               }
               if (agitando(8) && (!seleccion[0] || !seleccion[1] || !seleccion[2] || !seleccion[3] || !seleccion[4]) ) {      //Falta agregar la condicion de dados no seleccionados
                  if (!seleccion[0]) printf("1 ");
                  if (!seleccion[1]) printf("2 ");
                  if (!seleccion[2]) printf("3 ");
                  if (!seleccion[3]) printf("4 ");
                  if (!seleccion[4]) printf("5 \r\n");

                  estado = sacudiendo;
               }

            break;

            case sacudiendo:
               if(dados[0]==0) srand (seedinicio*seedreposo);
                estadoAnt = sacudiendo;
                //Randomizar dados no seleccinados y dibujarlos.
                //falta implementar la fora de randomizar y escribir el arreglo que va a tener el numero de los dados
               ili9341_spi_init(100000000);
               while (agitando(0.1)){
                for (int i = 1; i < 6; i++){
                    if (!seleccion[i-1]){
                       ili9341_drawDadoNumero(display, i, (rand())%6+1);
                     }
                }
                printf("Sacudiendooooo \r\n");
                veces++;
                reproducirSacudir();
               }
                if(!agitando(0.1) && veces >= 3){
                        estado = reposo;
                        veces = 0;
                }
                break;

            default:
                break;
            }
        delay_ms(25);
    }




    
   
}

/* 1MS Timer callback */

void inicializacion(void){
    boardConfig();
    ili9341_gpio_init();
    ili9341_spi_init(100000000);
    tickConfig(1);
    tickCallbackSet(diskTickHook, NULL);

    // Inicializaci n y configuraci n del display ILI9341
    
    const ili9341_cfg_t display_cfg = {
        .cs_pin = gpio_cs_pin,
        .dc_pin = gpio_dc_pin,
        .rst_pin = gpio_rst_pin,
        .spi_tx_dma = spi_tx_dma_b,
        .spi_tx_ready = spi_tx_dma_ready,
        .orientation = ILI9341_ORIENTATION_HORIZONTAL_UD,
        .width = 320,
        .height = 240,
        .timeout_ms = 10000,
        .wup_delay_ms = 20,
        .restart_delay_ms = 20};

    const ili9341_hw_cfg_t hw_cfg = ili9341_get_default_hw_cfg();

    display = ili9341_init(&display_cfg, &hw_cfg);
    if (display == NULL)
    {
        // Error_Handler();
    }

    //Inicializacion del XPT2046
    if(!XPT2046_Touchscreen_begin()){
        printf( "Error al Inicializar el Touch.");
    }
    valPantalla.firsttouch=false;
    valPantalla.x=-1;
    valPantalla.y=-1;
    valPantalla.z=-1;
    valPantalla.amount=0;
    valPantalla.tolerancia=0;
    valPantalla.firsttouch=false;

    //Aca va la inicializacion del MPU
    mpu6050Init();

    //Aca va la inicializacion del AmpOp de sonido
    inicializarParlante();
    tirada=nada;
    suma=0;
    estado=inicio;
    estadoAnt=apagado;
    seedinicio=0;
    seedreposo=0;
    
    return;
}

void LeerPantalla(void){
   ili9341_spi_init(400000);
   XPT2046_Touchscreen_readData(&valPantalla);  //Esto puede quedar aca o dentro de los cases
   ili9341_spi_init(100000000);
}

Juego CalcularJuego(uint8_t *dados,uint8_t *puntaje){
   uint8_t histograma[6]={0,0,0,0,0,0};
   uint8_t nmax=0,puntmax=0;
   uint8_t histohisto[6]={0,0,0,0,0,0};
   bool seis=false,uno=false;
   for (int i = 0; i < 5; i++){
      histograma[dados[i]-1]++;
      if(dados[i]==6) seis=true;
      if(dados[i]==1) uno=true;
   }
   for (int i = 0; i < 6; i++){
      if(puntmax<(histograma[i])*(i+1)){
         puntmax=(histograma[i])*(i+1);
         nmax=(i+1);
      }
      histohisto[histograma[i]]++;
   }
   //Si es generala
   if(histohisto[5]==1) {
      *puntaje=50;
      return generala;
   }
   //Si es poker
   if(histohisto[4]==1){
      *puntaje=40;
      return poker;
   }
   //Si es full
   if(histohisto[3]==1 && histohisto[2]==1){
      *puntaje=30;
      return full;
   }
   //Si es escalera mayor o menor
   if(histohisto[1]==5){
      if(seis && !uno){
         *puntaje=25;
         return emayor;
      }
      if(!seis && uno){
         *puntaje=20;
         return emenor;
      }
   }
   *puntaje=puntmax;
   switch(nmax){
      case 1:
         return j1;
         break;
      case 2:
         return j2;
         break;
      case 3:
         return j3;
         break;
      case 4:
         return j4;
         break;
      case 5:
         return j5;
         break;
      case 6:
         return j6;
         break;
   }
   *puntaje=0;
   return nada;
}

void diskTickHook(void *ptr){
    /* Update Display driver timers. */
    ili9341_1ms_timer_cb();
}

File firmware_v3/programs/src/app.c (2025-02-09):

#include "../inc/app.h"

#include "ili9341.h"
#include "sapi.h"
#include "XPT2046_Touchscreen.h"

typedef enum {inicio,reposo,sacudiendo,apagado} State;

TS_Point valPantalla;
State estado,estadoAnt;

void inicializacion(void);

int main(void) {

    inicializacion();
    

    // C digo de aplicacion
    while(1){
        //Lecturas de los perifericos
        XPT2046_Touchscreen_readData(valPantalla);  //Esto puede quedar aca o dentro de los cases
        //Aca tiene que ir la lectura del MPU para ver si se esta moviendo

        //MEF de control del dibujito
        switch (estado){
            case inicio:
                if (estadoAnt!= inicio)
                    //dibujo de menu principal con nombre de juego y boton de "iniciar"
                    ili9341_spi_init(100000000);
                    ili9341_paintBackground(display, 0);
                    ili9341_setTextSize(5);
                    ili9341_setCursor(0, 10);
                    ili9341_setTextColor(0xdaa0, 0);
                    ili9341_printStr(display, "GENERATOR");

                    ili9341_drawRectangle(display, 60, 140, 200, 40, 0xdaa0);
                    ili9341_setTextSize(3);
                    ili9341_setCursor(110, 150);
                    ili9341_setTextColor(0, 0xdaa0);
                    ili9341_printStr(display, "Iniciar");

                    estadoAnt = inicio;
                    leerTouch();

                if (InStart(valPantalla)){
                    estado = reposo;
                }
            break;
            case reposo:
                if ((estadoAnt != reposo)&&(estadoAnt != sacudiendo)){
                    //dibujar el fondo y borde de dados

                    ili9341_spi_init(100000000);
                    ili9341_paintBackground(display, 0xfd35);
                    ili9341_setDadoFondo(0xFFFF);
                    ili9341_setDadoBorde(0);
                    for (int i = 1; i < 6; i++){
                        ili9341_drawDadoBase(display, i);
                    }
                }
                estadoAnt = reposo;

                if (no es la primera vez)
                {
                    // Seleccionar todos los dados
                    ili9341_spi_init(100000000);
                    for (int i = 1; i < 6; i++){
                        ili9341_seleccionarDado(display, i, 0);
                    }
                    //Imprimir nombre del juego
                    //acá falta implementar la funcion que calcule estas dos cosas
                    ili9341_setTextSize(3);
                    ili9341_setCursor(110, 30);
                    ili9341_setTextColor(0xFFFF, 0xfd35);
                    ili9341_printStr(display, "NombreJuego");

                    //Imprimir puntaje

                    ili9341_setTextSize(5);;
                    ili9341_setCursor(130, 180);
                    ili9341_printStr(display, "50");

                    int16_t dado=SelectDado(valPantalla);
                    if(dado){
                        Selecciono/deselecciono el dado
                        Y dibujo la seleccion
                    }

                }

                
                if(Se sacude && algun dado sin seleccionar){
                    veces++;
                    if veces>5 {
                        estado = sacudiendo;
                        veces = 0;
                    }
                }

                break;

            case sacudiendo:
                estadoAnt = sacudiendo;

                //Randomizar dados no seleccinados y dibujarlos.
                //falta implementar la fora de randomizar y escribir el arreglo que va a tener el numero de los dados

                ili9341_spi_init(100000000);
                for (int i = 1; i < 6; i++){
                    ili9341_drawDadoNumero(display, i, 6);
                }
                cada(x veces){
                    Reproducir sonido
                }

                if(NO Se sacude){
                    veces++;
                    if veces>5 {
                        estado = reposo;
                        veces = 0;
                    }
                }

                break;

            default:
                break;
            }
        wait(0.25s);
    }




    
   
}

/* 1MS Timer callback */

void inicializacion(void){
    boardConfig();
    ili9341_gpio_init();
    ili9341_spi_init(100000000);
    tickConfig(1);
    tickCallbackSet(diskTickHook, NULL);

    // Inicializaci n y configuraci n del display ILI9341
    ili9341_desc_ptr_t display;
    const ili9341_cfg_t display_cfg = {
        .cs_pin = gpio_cs_pin,
        .dc_pin = gpio_dc_pin,
        .rst_pin = gpio_rst_pin,
        .spi_tx_dma = spi_tx_dma_b,
        .spi_tx_ready = spi_tx_dma_ready,
        .orientation = ILI9341_ORIENTATION_HORIZONTAL_UD,
        .width = 320,
        .height = 240,
        .timeout_ms = 10000,
        .wup_delay_ms = 20,
        .restart_delay_ms = 20};

    const ili9341_hw_cfg_t hw_cfg = ili9341_get_default_hw_cfg();

    display = ili9341_init(&display_cfg, &hw_cfg);
    if (display == NULL)
    {
        // Error_Handler();
    }

    //Inicializacion del XPT2046
    if(!XPT2046_Touchscreen_begin()){
        printf( "Error al Inicializar el Touch.");
    }
    valPantalla.firsttouch=false;
    valPantalla.x=-1;
    valPantalla.y=-1;
    valPantalla.z=-1;

    //Aca va la inicializacion del MPU

    //Aca va la inicializacion del AmpOp de sonido

    estado=reposo;
    estadoAnt=apagado;
    return;
}

void diskTickHook(void *ptr){
    /* Update Display driver timers. */
    ili9341_1ms_timer_cb();
}

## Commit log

2024-10-10 commit inicial
    [app.names.csv]
2024-10-14 correcciones de la clase del 14/10
    [app.names.csv]
2024-10-15 agregado un codigo de error para la funcion draw_pixel
2024-10-15 agregado codigo para probar libreria
2024-10-15 Modificacion en draw_pixel, implementacion de drawVLine y drawHLine
2024-10-15 Ya fue, portee directo el _writeLine
2024-10-26 Subi la carpeta firmware_v3
    [CIAA-Z3R0 bom_v0.2.xls, app.names.csv, lpc4337.cfg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]
2024-10-27 Aca esta lo que subio rama
2024-10-27 Avances en el driver del mpu
2024-10-28 Avances en clase: solucion de errores de la libreria
2024-10-30 Agrego primer borrador de librería
2024-10-31 agregado archivos de kicad
2024-10-31 fotos kicad
2024-11-01 Agrego bases para driver del touch
2024-11-01 Agregado "TP1" a carpeta kicad
    [TP1.kicad_pcb, TP1.kicad_sch]
2024-11-01 Agragados PDFs de kicad
2024-11-01 Actualizacion de Proyecto KiCad
    [TP1.kicad_sch]
2024-11-04 Cambio del programa de prueba, ahora usar la libreria MPU60X0 de sAPI
2024-11-06 Ajuste de valores de configuración de hardware por default
2024-11-07 Actualizacion de KiCad
    [TP1.kicad_pcb, TP1.kicad_sch]
2024-11-11 Actualizacion Kicad
    [TP1.kicad_pcb, TP1.kicad_sch]
2024-11-11 patch kicad
2024-11-11 patch 2
    [TP1.kicad_pcb]
2024-11-11 Agregadas pruebas de funciones de línea y píxel, trabajando en funciones para mostrar texto
2024-11-11 Agregadas funcionalidades de impresión de texto
2024-11-14 Incorporando spi en Touch
2024-11-14 Sacar acentto
    [TP1.kicad_pcb]
2024-11-15 Correcciones de la clase
2024-11-20 Primera version de prueba del touch
2024-11-24 Listo para probar
2024-11-30 Correcciones para que ande
2024-12-05 Configurado de pines
2024-12-05 Cambios de configuracion de pines
2024-12-06 Ahora la acceleracion se mide por magnitud, para que no importela inclinacion del dispositivo
2024-12-06 Ahora se toma en cuenta la medicion anterior para que la deteccion sea mas realista
2024-12-07 Se agrego el sonido de victoria
2024-12-08 Correccion de errores
2024-12-08 Prueba impresión de imagen
2024-12-08 Prueba impresion de imagen con memoria dinamica
2024-12-11 Emprolijamiento de estructuras de datos en táctil
2024-12-12 Código que hace UNA interrupción
2024-12-13 Hechas funciones para dibujar la base de los dados, modificar los colores y dibujar los puntos
2024-12-14 Prueba impresión de dados
2024-12-17 Pruebas en la interrupción
2025-01-10 Modificacion de funciones para imprimir líneas horizontales y verticales + programa de prueba. Cambio menor en funciones para settear los colores de los dados
2025-01-11 Simplificación y reestructurado de función "ili9341_randomizar_dado" a "ili9341_dibujar_dado_numero"
2025-01-11 Parche (ajuste de dibujos de dados)
2025-01-14 Correcion de sintaxis
2025-01-31 cambio de parametros
2025-02-04 PROBAR: Simplificación de fución ili9341_spi_init(bitRate);
2025-02-04 Implementación de ili9341_paint_background();
2025-02-08 Se actualizo la libreria mpu6050
2025-02-09 Se creo la libreria sonidos
2025-02-09 Borron del menú de inicio
2025-02-09 Deteccion de botones y dados en pantalla
2025-02-09 Primera pantalla de Inicio responsive
2025-02-10 Ajuste del boton de inicio
2025-02-10 Correcciones del CAD
    [TP1.kicad_pcb, TP1.kicad_sch]
2025-02-11 Seleccion de Dados y Calculo de Juegos y Puntajes
2025-02-11 Cambios en la libreria del mpu
2025-02-11 Se agregaron efectos de sonido
2025-02-12 Correccion de multiples selecciones
2025-02-13 Parche en calculo de escalera
2025-02-17 Correcciones color de fondo de texto
